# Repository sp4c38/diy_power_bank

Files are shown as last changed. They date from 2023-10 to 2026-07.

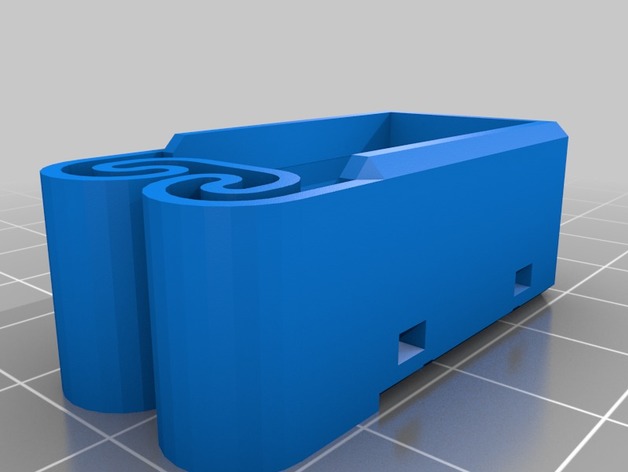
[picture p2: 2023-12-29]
3D Printed Parts/Battery Holder/Try 1/Flexing_battery_holders_with_integrated_spring_456900/images/flexbatter14250x1.jpg

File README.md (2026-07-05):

# DIY Power Bank

This repository contains the project files for my custom power bank, including the PCB design and fabrication files, firmware, iOS app, and 3D-printable enclosure parts.

The files are provided for anyone interested in the project or who wants to learn from it. This is not a complete step-by-step build guide.

[Project showcase](https://www.space8.me/custom-power-bank.html)

Lithium-ion batteries can be dangerous. The files are provided as-is and should only be used with appropriate knowledge and safety precautions.

## License

This project is available under the [MIT License](LICENSE).

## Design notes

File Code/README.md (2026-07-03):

# Powerbank Firmware and App

Firmware for the Arduino Nano 33 BLE that supervises the BQ76920-based power
bank PCB, plus the native SwiftUI iOS app that talks to it over BLE.

## Layout

- `PowerbankFirmware/` - Arduino sketch and C++ source files.
- `Powerbank/` - SwiftUI iOS app.
- `Getting Started with Bluetooth Low Energy.pdf` - BLE reference material.
- `requirements.txt` - historical dependency note from the old setup.

## Firmware Architecture

- `Bq76920Driver` owns CRC I2C, calibration, raw ADC reads, FET control,
  protection registers, balancing, fault clearing and SHIP mode.
- `PackMonitor` converts/filter readings and marks telemetry untrusted if cell
  measurements jump or become implausible.
- `SafetyPolicy` decides whether charge, discharge and balancing are allowed.
- `Balancer` performs conservative one-cell-at-a-time passive balancing.
- `PowerManager` turns the output off after idle and requests SHIP after very
  long idle.
- `BLEApp` exposes telemetry and guarded commands to the iOS app.
- `SerialConsole` mirrors the app commands for bench testing.

## Board

- Board: Arduino Nano 33 BLE
- FQBN: `arduino:mbed_nano:nano33ble`
- Current serial port: `/dev/cu.usbmodem112201`
- Serial baud rate used by the old firmware: `9600`

## Dependencies

Installed through Arduino CLI:

- `ArduinoBLE`
- `ArduinoLog`

## Useful Commands

List connected boards:

```sh
'/Applications/Arduino IDE.app/Contents/Resources/app/lib/backend/resources/arduino-cli' board list
```

Open the serial monitor:

```sh
'/Applications/Arduino IDE.app/Contents/Resources/app/lib/backend/resources/arduino-cli' monitor -p /dev/cu.usbmodem112201 -c baudrate=9600
```

Serial commands:

- `help` - print the command list.
- `status` - print state, FET status, current, pack voltage, die temperature and cell voltages.
- `faults` - print BQ76920 fault/status bits.
- `raw` - print raw ADC/register diagnostics.
- `clear_faults` - clear UV, OV, SCD and OCD fault bits.
- `output_on` / `output_off` - request the normal discharge/output path.
- `ship!` - enter BQ76920 SHIP mode. The `!` is intentional confirmation.
- `charge_on!` / `charge_off` - developer CHG FET override.
- `balance_off` - force all cell balancing off.

Balancing is automatic only when readings are trusted, cells are near the top of
charge, current is near idle, and only one cell needs bleeding.

Compile the firmware:

```sh
'/Applications/Arduino IDE.app/Contents/Resources/app/lib/backend/resources/arduino-cli' compile --fqbn arduino:mbed_nano:nano33ble Code/PowerbankFirmware
```

Upload the firmware:

```sh
'/Applications/Arduino IDE.app/Contents/Resources/app/lib/backend/resources/arduino-cli' upload -p /dev/cu.usbmodem112201 --fqbn arduino:mbed_nano:nano33ble Code/PowerbankFirmware
```

Build the iOS app:

```sh
xcodebuild -project Code/Powerbank/Powerbank.xcodeproj -scheme Powerbank -destination 'platform=iOS Simulator,name=iPhone 17' build
```

## BLE Protocol

Service UUID: `7E571000-40A1-4E31-8E9D-4AC0D8B2A100`

- Telemetry: `7E571001-40A1-4E31-8E9D-4AC0D8B2A100`, read + notify, packed
  little-endian protocol v3 payload. Protocol v2 added full-resolution charge;
  v3 adds the idle-shutdown countdown and new state flags.
- Command: `7E571002-40A1-4E31-8E9D-4AC0D8B2A100`, write, two bytes:
  command id and optional confirmation byte `0xA5`.
- Command result: `7E571003-40A1-4E31-8E9D-4AC0D8B2A100`, read + notify,
  UTF-8 status text.
- Device info: `7E571004-40A1-4E31-8E9D-4AC0D8B2A100`, read, UTF-8 firmware
  and protocol version.
- History control: `7E571005-40A1-4E31-8E9D-4AC0D8B2A100`, read + write +
  notify, requests resumable history streaming and reports the retained range.
- History data: `7E571006-40A1-4E31-8E9D-4AC0D8B2A100`, notify, packed
  ten-minute samples and state-change snapshots split into ordered 20-byte
  chunks so transfer does not depend on a larger negotiated BLE MTU.
- Battery health: `7E571007-40A1-4E31-8E9D-4AC0D8B2A100`, read + notify,
  learned capacity and lifetime aggregate metrics.
- Time sync: `7E571008-40A1-4E31-8E9D-4AC0D8B2A100`, write, Unix time from
  the connected app.

## Persistent Storage

Firmware v0.3 reserves the final 96 KB of internal flash (`0xE8000` through
`0xFFFFF`) for LittleFS. It stores gauge checkpoints, battery-health aggregates,
and a circular buffer of roughly 14 days of history. The firmware disables
storage if its image ever reaches the reserved region; protection and live
telemetry continue without persistence.

The gauge restores its last coulomb count after a restart, then checks it against
trusted resting voltage. Small differences are retained, medium differences are
corrected gradually, and large differences cause a safe voltage-based reseed.

## Bring-Up Notes

2026-06-26:

- Arduino Nano 33 BLE detected on `/dev/cu.usbmodem112201`.
- Firmware compiles and uploads with Arduino CLI.
- Upload may require manually double-tapping reset to enter bootloader mode.
- With cells inserted and BQ76920 booted, I2C/CRC communication works.
- Known-good idle serial baseline:

```text
Pack state: Idle; DSG: true; CHG: true; pack current: -5; pack voltage: 11334
Cell 1: 3787; Cell 2: 3775; Cell 5: 3770
```

- Longer idle observation with the USB-A output module connected is stable at
  roughly `-4` to `-6 mA`, caused by always-on LEDs on that module. This is
  acceptable during bring-up, but the firmware still needs a later low-power
  strategy so that LED load cannot drain the battery pack empty.

Earlier in bring-up, a poorly seated cell/contact produced `Cell 2: 50` and
the firmware correctly disabled discharge. Reseating fixed the reading.

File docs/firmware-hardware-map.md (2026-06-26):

# Firmware Hardware Map

This document captures the firmware-relevant facts extracted from the KiCad
schematic/netlist and existing firmware. It is intended as the starting point
for the power-bank firmware rewrite/audit.

## Source Evidence

- Main schematic: `Circuit/KiCAD Circuit/Powerbank.kicad_sch`
- KiCad netlist export: `Circuit/KiCAD Circuit/Powerbank.xml`
- BOM export: `Circuit/KiCAD Circuit/Bill of Materials.csv`
- Existing firmware: `Code/PowerbankFirmware`

Important caveat: `Powerbank.xml` was exported on 2024-01-12, while the KiCad
project and BOM appear to have changed later. Use this map as a firmware guide,
but verify anything safety-critical against the current schematic/board before
depending on it.

## Main Components

| Ref | Part | Firmware relevance |
| --- | --- | --- |
| U1 | BQ7692003PW | 3-5 cell Li-ion monitor/protector with I2C, CRC, FET control, cell voltage, pack voltage, current, temperature, protection, and balancing registers. |
| U2 | Arduino Nano 33 IoT socket | Firmware host. Current firmware uses Arduino APIs, Wire/I2C, serial logging, and optional ArduinoBLE. |
| Q1, Q3 | IRLB4132PBF NMOS | Pack-side protection FET network controlled through BQ76920 `DSG`/`CHG` circuitry. |
| Q2 | PMOS | Part of charge/discharge gate-control network. |
| R2 | 8 milliohm shunt | Current sense resistor for BQ76920 coulomb/current measurement. |
| SW1 | Pushbutton | Connected into the `TS1`/`VC1` area; likely used for boot/wake behavior. Confirm exact intended behavior before firmware relies on it. |
| SW2 | SPST switch | Connects the switched high-side supply path to Arduino `VIN`. |

## Arduino Pin Map

| Arduino pin | Net / target | Firmware use |
| --- | --- | --- |
| A4 / SDA | BQ76920 `SDA` | I2C data. |
| A5 / SCL | BQ76920 `SCL` | I2C clock. |
| D10 | BQ76920 `ALERT` | Alert/fault signal. Current firmware defines `ALERT_PIN = 10`, but does not actively use an interrupt yet. |
| VIN | Connected through `SW2` | Arduino supply input through the external switch path. |
| GND | Pack/BQ ground | Common reference with BQ76920 `VSS`. |

Unconnected in the netlist: Arduino `3V3`, `+5V`, `A0-A3`, `A6-A7`, `D0-D9`
except `D10`, `D11-D13`, and reset pins. That means the firmware should assume
the Arduino mainly talks to the board over I2C plus `ALERT`; it does not appear
to directly control the USB modules, buck converter, or other external modules.

## Pack Topology

The schematic/netlist describes a 3-cell series pack:

| Physical node | Netlist evidence | BQ76920 sense node |
| --- | --- | --- |
| Pack positive / cell 1 positive | `PACK +`, `CELL_1 +` | Through `Rc1` to `VC5` |
| Cell 1 negative / cell 2 positive | `CELL_1 -`, `CELL_2 +` | Through `Rc2` to tied `VC2`, `VC3`, `VC4` |
| Cell 2 negative / cell 3 positive | `CELL_2 -`, `CELL_3 +` | Through `Rc3` to `VC1` |
| Cell 3 negative / pack/BQ ground | `CELL_3 -`, `GND` | Through `Rc4` to `VC0` / `VSS` |

This matches the existing firmware reading `VC1_HI`, `VC2_HI`, and `VC5_HI`.
The cell labels in firmware should be made explicit because the BQ register
names do not read like physical cell numbers in this 3S configuration.

Proposed firmware naming:

| Firmware name | BQ reading | Physical voltage |
| --- | --- | --- |
| `cellBottomMv` | `VC1` | Bottom cell, between `VC1` and `VC0` |
| `cellMiddleMv` | `VC2` | Middle cell, between `VC2` and `VC1` |
| `cellTopMv` | `VC5` | Top cell, between `VC5` and tied `VC2/VC3/VC4` |

## BQ76920 Connections

| BQ76920 pin/function | Netlist connection | Firmware implication |
| --- | --- | --- |
| `SDA` | Arduino `A4_SDA` | Use `Wire` at BQ address `0x08` with CRC enabled. |
| `SCL` | Arduino `A5_SCL` | Current firmware uses 100 kHz I2C. |
| `ALERT` | Arduino `D10`, pull/filter network `R4`/`C4` | Should be monitored, ideally by interrupt or periodic read. |
| `SRP` / `SRN` | Across 8 milliohm current-sense path via `R1`/`R3` and filter caps | Current calculation must use 8 milliohm sense resistance. |
| `BAT` / `REGSRC` | Through `Rf1`, `Cf1`, diode/resistor network | BQ supply / pack voltage measurement path. |
| `REGOUT` | `C9` decoupling | Internal LDO output; do not treat as Arduino supply unless verified. |
| `CAP1` | `C7` decoupling | BQ internal charge-pump support. |
| `TS1` | `R5`, `R6`, `C5`, `SW1` network | Current firmware reads internal die temperature by keeping `TEMP_SEL = false`; external thermistor behavior needs verification. |
| `CHG` | Q2 source / gate-control network | Controls charge FET behavior indirectly. |
| `DSG` | Q1 gate through `R7` | Controls discharge FET behavior. |

## Protection FET / Pack Path

The netlist shows a low-side protection/sense arrangement:

- `PACK -` connects to Q3 source and `R8`.
- Q1 and Q3 drains are tied together.
- Q1 source connects to the current-sense/shunt side through R2 and the SRN
  filter network.
- BQ `DSG` drives Q1 gate through the `R7` network.
- BQ `CHG` drives Q2, which in turn affects Q3 gate through the `R8` network.

Firmware should therefore treat `DSG_ON` and `CHG_ON` as the authoritative BQ
control bits for enabling/disabling discharge and charge. It should not assume
direct Arduino GPIO control of the power path.

## Existing Firmware Constants To Recheck

Current values in `Code/PowerbankFirmware/register.h`:

| Constant | Current value | Meaning |
| --- | ---: | --- |
| `upperVoltageLimit` | 4190 mV | Firmware charge/balance limit. |
| `lowerVoltageLimit` | 2600 mV | Firmware discharge cutoff threshold. |
| `cvCurrentCutOff` | 200 mA | Constant-voltage completion threshold. |
| `allowedBalancingDifference` | 30 mV | Cell delta before balancing starts. |
| `balancingDifference` | 5 mV | Cell delta target before balancing stops. |
| `dischargingThreshold` | -50 mA | Current below this is considered discharging. |
| `currentSenseResistance` | 8 milliohm | Matches BOM value for R2. |
| `I2C_BQ76920_ADDRESS` | `0x08` | BQ7692003PW with CRC enabled. |
| `ALERT_PIN` | `10` | Matches Arduino D10 connection. |

These are plausible, but should be reviewed before final firmware because they
define real battery safety behavior.

## Existing Code Cross-Check

The old firmware is useful evidence because it reportedly worked on the real
PCB. Comparing it against the schematic/netlist shows that the core assumptions
line up:

| Topic | Existing firmware | Circuit evidence | Result |
| --- | --- | --- | --- |
| BQ device/address | `I2C_BQ76920_ADDRESS = 0x08` | `U1 = BQ7692003PW`, CRC-enabled variant expected by comments/code | Consistent. |
| I2C pins | `SDA_PIN = 18`, `SCL_PIN = 19`; `Wire.begin()` uses board defaults | BQ `SDA` -> Arduino `A4_SDA`, BQ `SCL` -> Arduino `A5_SCL` | Consistent. Pin constants are currently documentation only. |
| Alert pin | `ALERT_PIN = 10` | BQ `ALERT` -> Arduino `D10` | Consistent, but old firmware does not actively use the pin. |
| Current shunt | `currentSenseResistance = 8` milliohm | BOM: `R2 = 8m`; netlist places R2 in the SRP/SRN current path | Consistent. |
| Cell readings | Reads `VC1_HI`, `VC2_HI`, `VC5_HI` | 3S topology uses BQ nodes `VC0`, `VC1`, tied `VC2/VC3/VC4`, and `VC5` | Consistent. |
| Balancing bits | Uses `CB1`, `CB2`, `CB5` | Same BQ cell nodes used for the 3S measurement stack | Consistent with the selected BQ nodes. |
| FET control | Uses BQ `SYS_CTRL2` bits `DSG_ON` and `CHG_ON` | BQ `DSG` and `CHG` feed the MOSFET gate-control network | Consistent. |
| Temperature mode | `TEMP_SEL = false`; reads `TS1_HI` as internal die temperature | TS1 has a resistor/capacitor/switch network, but old code worked with internal temperature mode | Consistent for old behavior; external temperature use remains unverified. |
| Boot/shutdown | Assumes BQ is already booted; implements BQ SHIP sequence | Hardware includes `SW1`/`SW2`, and Arduino has no direct GPIO control of the power path | Consistent with manual wake/power hardware. |

No hardware-code mismatch was found in the essential firmware-facing
connections. The things to improve are mostly software robustness, clarity, and
power management rather than correcting the basic hardware model.

Live bring-up on 2026-06-26 confirmed this: after reseating the cells, the BQ
reported a stable idle baseline of about 11.33 V pack voltage with cell readings
`VC1=3787 mV`, `VC2=3775 mV`, and `VC5=3770 mV`; both `DSG` and `CHG` were on,
and current was near zero.

Minor code issues to clean up later, without changing hardware assumptions:

- `readRegisters()` and `writeRegister()` accept an I2C address parameter but
  internally use the global BQ address in a couple of places. This is harmless
  for this single-chip project, but confusing.
- Cell labels are currently logged as `Cell 1`, `Cell 2`, and `Cell 5`, matching
  BQ register names rather than a user-facing 3-cell pack view.
- `ALERT_PIN` is defined but not yet used for interrupt-driven fault handling
  or low-power wake behavior.
- The firmware waits forever for serial in `setup()`, which was fine for bench
  testing but not for standalone use.

## BQ Registers Already Used

The existing firmware already touches these BQ76920 functions:

- `CC_CFG`: written to `0x19` during setup.
- `ADCGAIN1`, `ADCGAIN2`, `ADCOFFSET`: used for voltage calibration.
- `VC1_HI`, `VC2_HI`, `VC5_HI`: cell voltage readings.
- `BAT_HI`: pack voltage.
- `CC_HI`: current/coulomb-counter reading.
- `TS1_HI`: temperature reading.
- `SYS_STAT`: fault flags.
- `SYS_CTRL1`, `SYS_CTRL2`: ADC, CC, CHG, DSG, SHIP sequence.
- `PROTECT1`, `PROTECT2`, `PROTECT3`, `OV_TRIP`, `UV_TRIP`: protection thresholds.
- `CELLBAL1`: cell balancing.

## Firmware Design Implications

1. The Arduino should be treated as a supervisor/UI node. The BQ76920 is the
   actual battery protection and measurement device.
2. Serial-only firmware should come before BLE. We need a trusted status loop
   first: BQ init, readings, fault handling, FET state, and SHIP mode.
3. The `ALERT` pin should become part of the safety loop. Polling `SYS_STAT`
   alone is useful, but `ALERT` lets firmware react quickly and sleep more
   efficiently.
4. Current firmware reads only internal die temperature. If the TS1 network was
   intended as an external thermistor or wake button path, that behavior needs
   a bench check.
5. Low-power behavior must account for hardware outside firmware control. If
   USB modules or converters draw idle current independently, firmware sleep
   alone will not be enough.
6. The BQ SHIP mode sequence is already implemented and should be preserved,
   but we need a clear policy for when firmware enters it.
7. BLE should be telemetry-first: expose pack status, cell voltages, current,
   temperatures, FET states, faults, balancing state, and uptime. Control
   commands should be restricted or guarded.

## Open Questions For Bench Verification

- Does `SW1` wake the BQ from SHIP mode, boot the pack, or serve another role?
- Does `SW2` fully remove Arduino power, or only switch part of the supply path?
- What is the actual idle current with CHG/DSG enabled and no load?
- What is the actual idle current with Arduino awake, asleep, BLE advertising,
  and BLE connected?
- Are the USB-A, USB-C, and buck modules powered from `PACK +` / `PACK -`
  after the protection FETs, and do they have enable pins not present in the
  KiCad netlist?
- Is there an external temperature sensor fitted, or should firmware only rely
  on BQ die temperature?
- Which physical cell should be displayed as cell 1 in the user interface:
  bottom-to-top electrical order, or the labels used in the schematic?

## Suggested First Firmware Milestone

Create a serial-only supervisor firmware that:

1. Initializes BQ76920 safely.
2. Verifies I2C/CRC communication.
3. Reads and prints all three cell voltages, pack voltage, current, temperature,
   `SYS_STAT`, and CHG/DSG state.
4. Exposes serial commands: `status`, `faults`, `clear_faults`, `ship`,
   `charge_on`, `charge_off`, `discharge_on`, `discharge_off`, and `balance_off`.
5. Keeps all balancing disabled unless explicitly testing it.
6. Never enables charge/discharge if voltage, current, temperature, or BQ fault
   status is outside the configured safety envelope.

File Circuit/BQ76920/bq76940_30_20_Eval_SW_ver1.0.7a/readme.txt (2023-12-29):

bqMAXIMO Windows installation software for bq769X0 AFEs

1. This program executes on Windows XP, Vista, and 7 32 or 64bit operating systems.  This installer assumes that a working EV2300 or EV2400 communications adapter with drivers is already installed on system.

2. Execute setup.exe.  This installs bqMAXIMO and all support components in c:\program files\Texas Instruments\bqMAXIMO directory.  A bqMAXIMO shortcut is placed on the desktop.  This shortcut can be used to execute the program after installation.  Other shortcuts are installed under "All Programs" "Texas Instruments".

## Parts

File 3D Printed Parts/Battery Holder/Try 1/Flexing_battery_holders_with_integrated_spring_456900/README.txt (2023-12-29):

Flexing battery holders with integrated spring by enif on Thingiverse: https://www.thingiverse.com/thing:456900

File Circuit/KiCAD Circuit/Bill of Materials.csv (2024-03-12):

Reference | Value | Footprint | Qty | DNP | Mouser
A1 | Arduino_Nano_33_IoT_Socket | Arduinos:Arduino_Nano_33_IoT_Socket | 1
C1,C2,C3,C6,C8 | 0.1uF | K104K10X7RF53H5:K104K10X7RF53H5_VIS | 5 |  | 594-K104K10X7RF53H5
C4 | 470pF | K471K10X7RF5UH5:K471K10X7RF5UH5_VIS | 1 |  | 594-K471K10X7RF5UH5
C5 | 4700pF | C410C472K1R5TA:CAP_C410C_AX_X7R_AXIMAX_KEM | 1 |  | 80-C410C472K1R
C7,Cc1,Cc2,Cc3,Cc4 | 1uF | K105K20X7RF5TH5:K105K20X7RF5TH5_VIS | 5 |  | 594-K105K20X7RF5TH5
C9 | 4.7uF | FG24X7R1E475KRT06:CAP_FG24_TDK | 1 |  | 810-FG24X7R1E475KRT6
Cf1 | 2.2uF | FG18X5R1E225KRT06:CAP_FG18_TDK | 1 |  | 810-FG18X5R1E225KRT6
D1,D2 | D | Custom Footprints:1N4149TR | 2 |  | 512-1N4149
D3 | TVS Diode 17.1V | Diode_THT:D_DO-41_SOD81_P7.62mm_Horizontal | 1 |  | 576-P4KE20A
H1 | BATT+ | Custom Footprints:Power Connection Pads | 1
H2 | BATT- | Custom Footprints:Power Connection Pads | 1
H7 | PACK+ | Custom Footprints:Power Connection Pads | 1
H8 | PACK- | Custom Footprints:Power Connection Pads | 1
J1 | EBWA-04-A | Custom Footprints:EBWA-04-A | 1 |  | 737-EBWA-04-A
Q1,Q3 | NMOS | Custom Footprints:IRLB4132PBF | 2 |  | 942-IRLB4132PBF
Q2 | PMOS | Custom Footprints:TO-92_MC_MCH | 1 |  | 689-VP3203N3-G
R1,R3,Rf1 | 100 | RNF14FTD100R:STA_RNF14_STP | 3 |  | 708-RNF14FTD100R
R2 | 8m | 14AFR008E:RES_14A_OHM | 1 |  | 588-14AFR008E
R4 | 499k | MFR-25FBF52-499K:YAG_MF25_YAG | 1 |  | 603-MFR-25FBF52-499K
R5,R6,Rd1,Rd2 | 10k | RNF18FTD10K0:STA_RNF18_STP | 4 |  | 708-RNF18FTD10K0
R7,R8 | 1M | MFR-25FRF52-1M:YAG_MF25_YAG | 2 |  | 603-MFR-25FRF521M
Rc1,Rc2,Rc3,Rc4 | 50 | CMF5550R000FKEK70:RES_CMF07_VIS | 4 |  | 71-CMF5550R000FKEK70
SW1 | SW_Push | Custom Footprints:Switch Pads | 1
SW2 | SW_SPST | Custom Footprints:Switch Pads | 1
U1 | BQ7692003PW | BQ7692003PW:PW0020A_N | 1 |  | 595-BQ7692003PW

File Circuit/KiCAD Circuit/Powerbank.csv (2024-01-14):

# | Reference | Qty | Value | Footprint | DNP
1 | C1, C2, C3, C6, C8, C10, C11 | 7 | 0.1μF
2 | C4 | 1 | 470pF
3 | C5 | 1 | 4700pF
4 | C7, Cc1, Cc2, Cc3, Cc4 | 5 | 1μF
5 | C9 | 1 | 4.7μF
6 | CELL_1, CELL_2, CELL_3 | 3 | ~
7 | Cf1 | 1 | 2.2μF
8 | D1, D3 | 2 | D
9 | D2 | 1 | TVS Diode 30V
10 | Q1, Q3 | 2 | NMOS
11 | Q2 | 1 | PMOS
12 | R1, R3, Rf1 | 3 | 100Ω
13 | R2 | 1 | 8mΩ
14 | R4 | 1 | 500kΩ
15 | R5, R6, Rd1, Rd2 | 4 | 10kΩ
16 | R7, R8 | 2 | 1MΩ
17 | Rc1, Rc2, Rc3, Rc4 | 4 | 50Ω
18 | SW1 | 1 | SW_Push
19 | SW2 | 1 | SW_SPST
20 | U1 | 1 | BQ7692003PW | BQ7692003PW:PW0020A_N
21 | U2 | 1 | Arduino_Nano_v3.x | Arduinos:Arduino_Nano_33_IoT_Socket

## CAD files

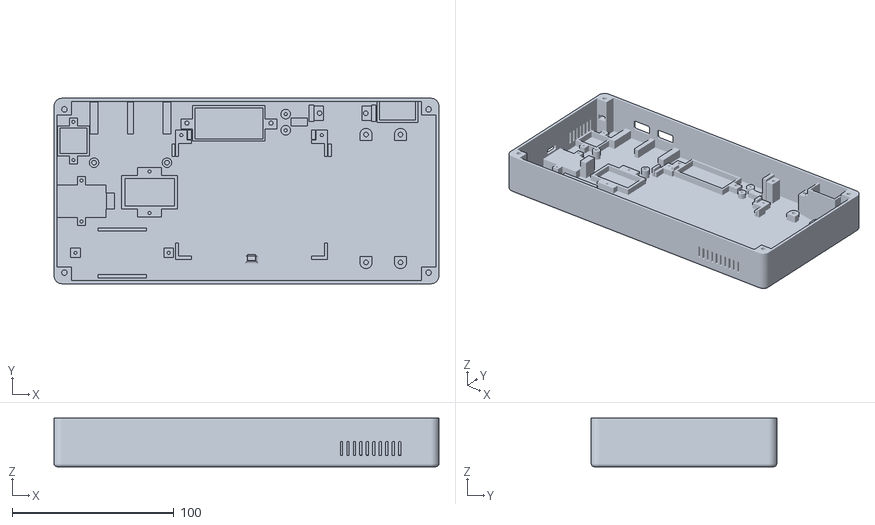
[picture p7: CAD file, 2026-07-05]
3D Printed Parts/Case/Base_Frame v169_Main Body.stl
238.0 x 114.7 x 30.0

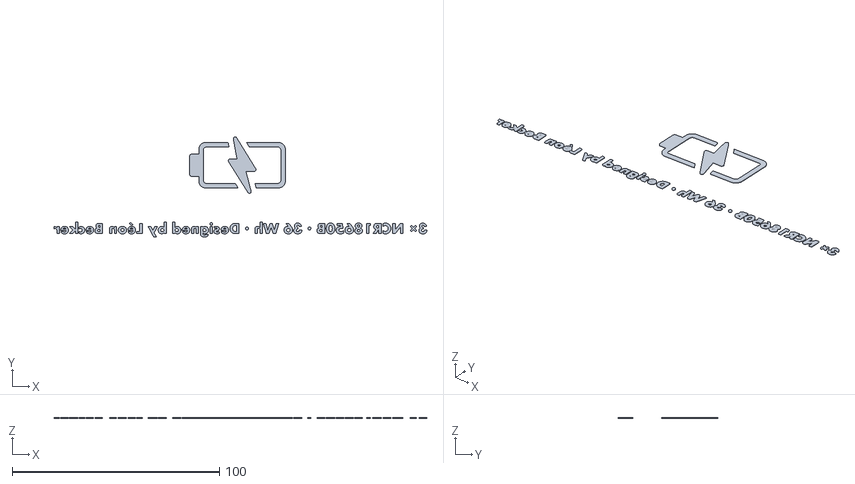
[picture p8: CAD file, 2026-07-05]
3D Printed Parts/Case/Main Body Bottom Text.stl
179.9 x 48.4 x 0.5

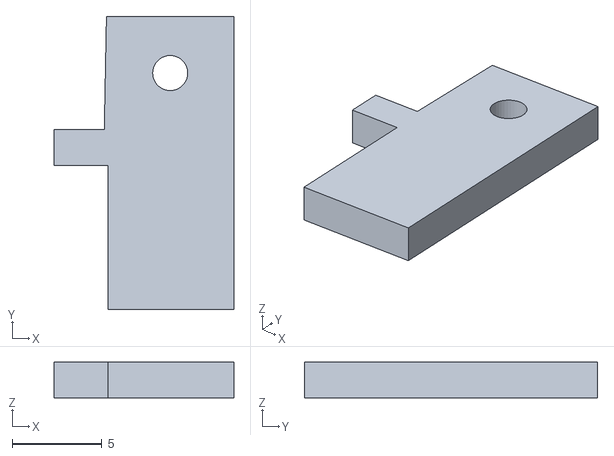
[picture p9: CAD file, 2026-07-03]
3D Printed Parts/Case/Base_Frame v169_Mainboard Holder 1.stl
10.0 x 16.3 x 2.00

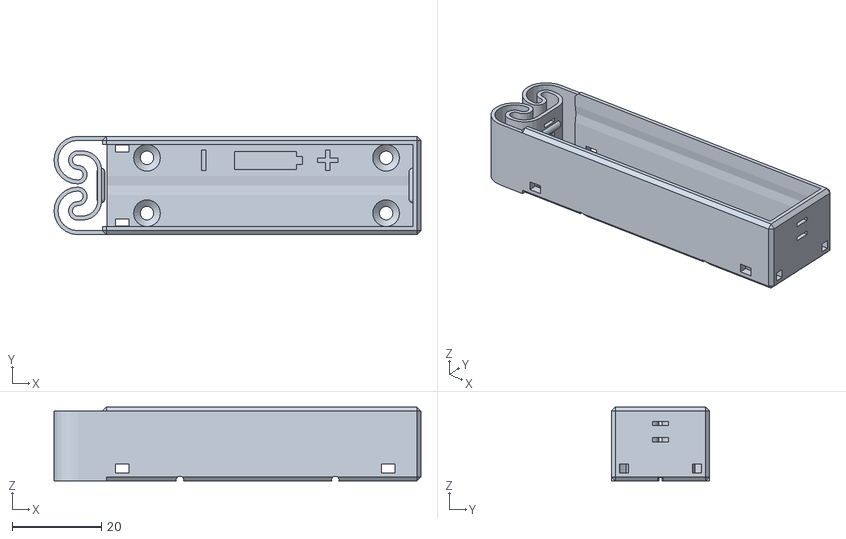
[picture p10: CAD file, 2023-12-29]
3D Printed Parts/Battery Holder/Try 1/1x NCR18650B Protected Holder.stl
82.1 x 22.0 x 16.5

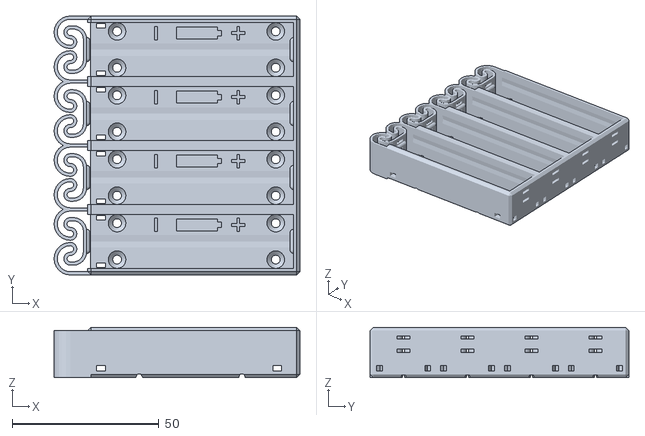
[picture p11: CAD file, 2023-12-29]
3D Printed Parts/Battery Holder/Try 1/Flexing_battery_holders_with_integrated_spring_456900/files/flexbatter18700x4.stl
83.7 x 88.2 x 17.2

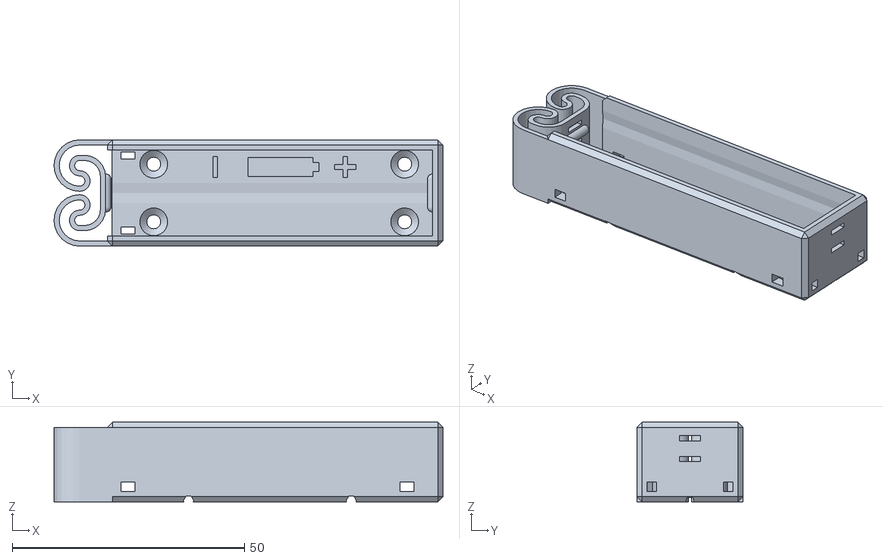
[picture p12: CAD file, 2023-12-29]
3D Printed Parts/Battery Holder/Try 1/Flexing_battery_holders_with_integrated_spring_456900/files/flexbatter18700x1.stl
83.7 x 22.9 x 17.2

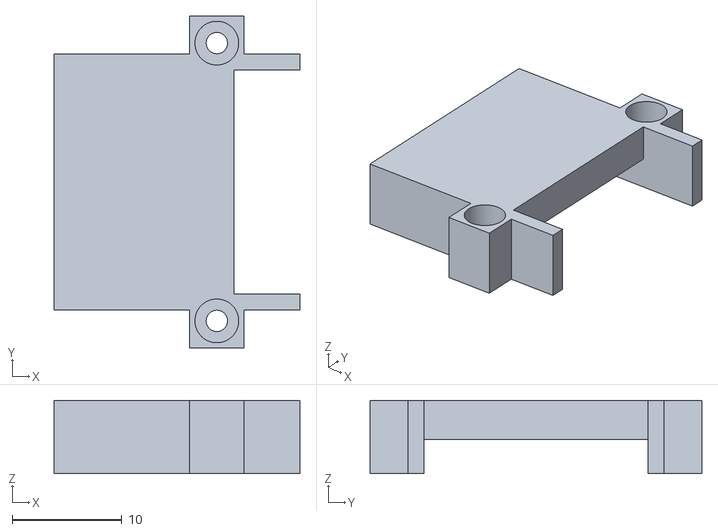
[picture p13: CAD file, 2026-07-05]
3D Printed Parts/Case/Base_Frame v169_USB-C Input Top.stl
22.4 x 30.3 x 6.70

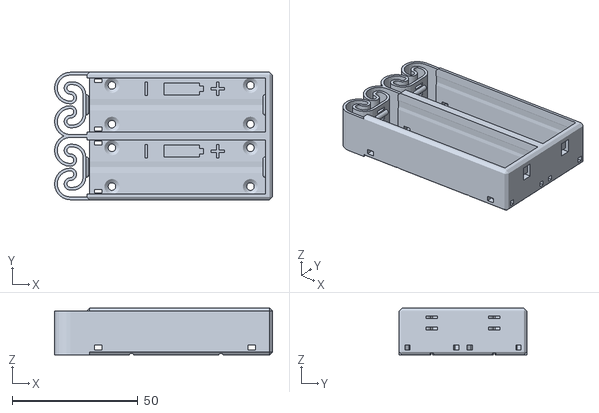
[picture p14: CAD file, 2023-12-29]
3D Printed Parts/Battery Holder/Try 1/Flexing_battery_holders_with_integrated_spring_456900/files/flexbatter21700x2.stl
86.6 x 50.6 x 18.5

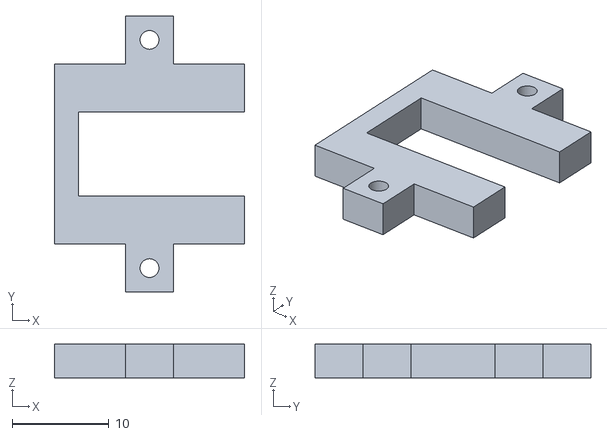
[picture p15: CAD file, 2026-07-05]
3D Printed Parts/Case/Base_Frame v169_Cable Hub Top.stl
19.7 x 28.6 x 3.50

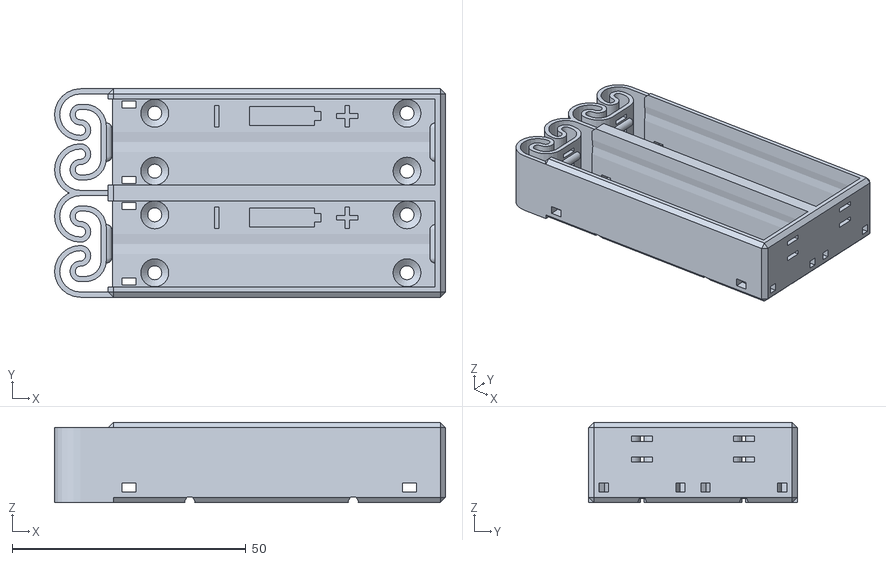
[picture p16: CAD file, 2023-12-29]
3D Printed Parts/Battery Holder/Try 1/Flexing_battery_holders_with_integrated_spring_456900/files/flexbatter18700x2.stl
83.7 x 44.6 x 17.2

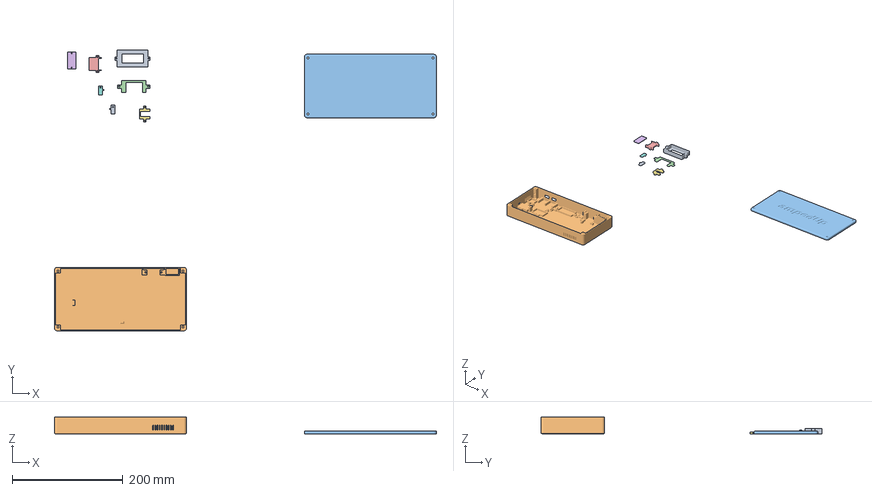
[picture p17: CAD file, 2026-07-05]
3D Printed Parts/Case/Case.3mf
688.5 x 506.1 x 30.0 mm
Base_Frame v169_Body116.stl
Base_Frame v169_Main Body
Lid.stl
Base_Frame v169_MOSFET Top.stl
Base_Frame v169_USB-C Input Top.stl
Base_Frame v169_Diode Cover.stl
Base_Frame v169_Cable Hub Top.stl
Base_Frame v169_Mainboard Holder 2.stl
Base_Frame v169_Mainboard Holder 1.stl

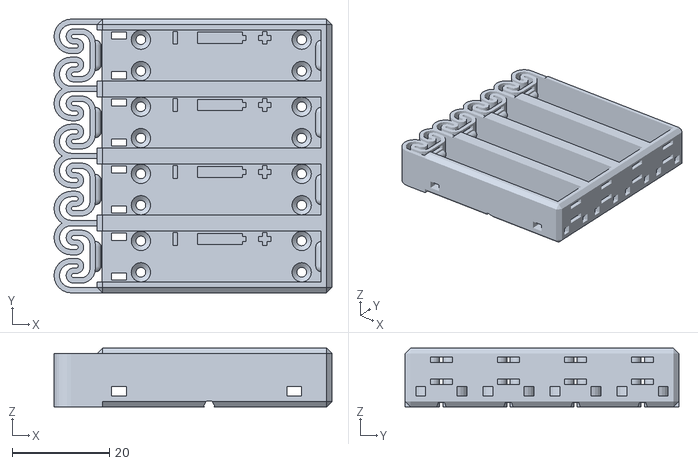
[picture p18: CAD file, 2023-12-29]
3D Printed Parts/Battery Holder/Try 1/Flexing_battery_holders_with_integrated_spring_456900/files/flexbatterAAAx4.stl
57.2 x 56.4 x 12.1

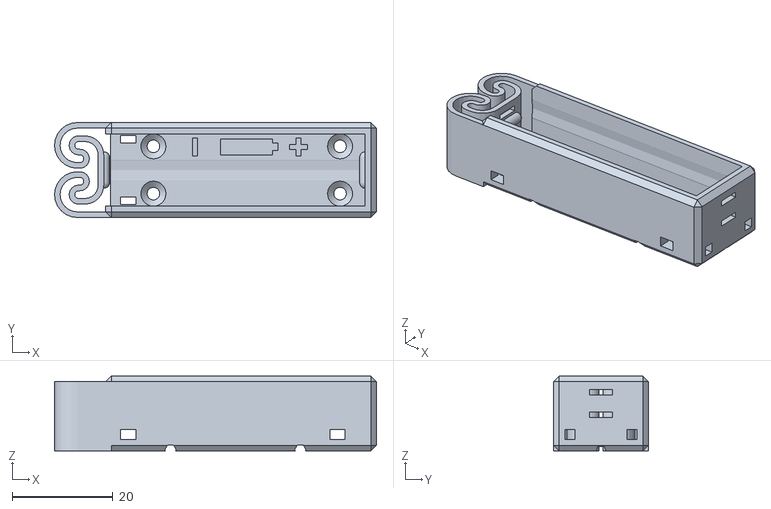
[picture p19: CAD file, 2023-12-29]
3D Printed Parts/Battery Holder/Try 1/Flexing_battery_holders_with_integrated_spring_456900/files/flexbatterAAx1.stl
64.0 x 18.9 x 14.9

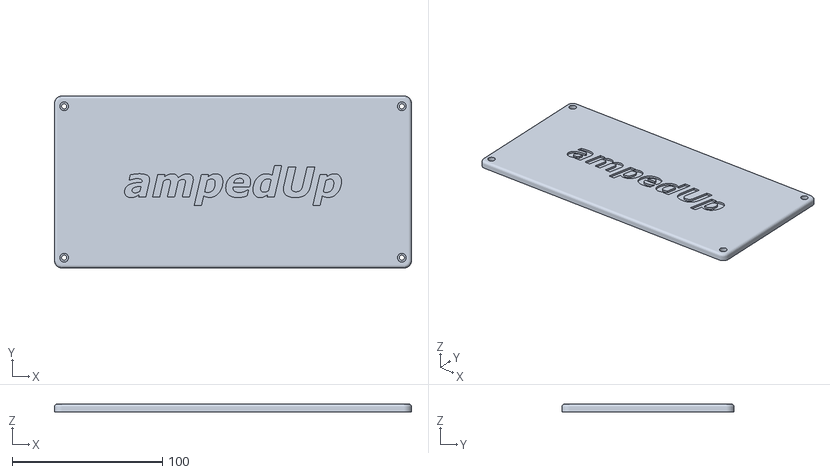
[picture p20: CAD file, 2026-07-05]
3D Printed Parts/Case/Lid.stl
238.0 x 114.7 x 5.50

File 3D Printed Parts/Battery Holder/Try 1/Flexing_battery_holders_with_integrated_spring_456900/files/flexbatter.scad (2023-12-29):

//////////////////////////////////////////////////////////////////////////////////////
///
///  FLEXBATTER: Flexing battery holder with built-in spring
///
///  This file generates battery holders for arbitrary cylindrical sizes.
///  The number of batteries and their size is fully parametrized.
///
///  The usual metallic spring at the minus pole is replaced by a
///  flexible printed spring, which is pressing the contacts firmly to 
///  the battery.
///
///  The contacts for the plus and minus pole can easily be made by
///  a few windings of the uninsulated ends of the connecting wires.
///  Each battery compartment contains are several holes to the outside
///  as well ad to the neighboring compartments, through which connecting
///  wires can be passed for easy configuring of parallel, serial or
///  balanced-serial battery packs.
///  
///  The preconfigured battery sizes are:
///  AA, AAA, C, D, 18650(Li-Ion), 18650P(protected Li-Ion), CR123A(16340)
///  
///  Given that the printed plastic spring needs to be flexible, ABS is the material
///  of choice here.
///
//////////////////////////////////////////////////////////////////////////////////////
///
///  2014-09-09 Heinz Spiess, Switzerland
///
///  released under Creative Commons - Attribution - Share Alike licence (CC BY-SA)
//////////////////////////////////////////////////////////////////////////////////////

// build a cube with chamfered edges
module chamfered_cube(size,d=1){
   hull(){
     translate([d,d,0])cube(size-2*[d,d,0]);
     translate([0,d,d])cube(size-2*[0,d,d]);
     translate([d,0,d])cube(size-2*[d,0,d]);
   }
}


// draw an arc width height h between radius r1..r2 and angles a1..a2
module arc(r1,r2,h,a1=0,a2=0){
     if(a2-a1<=180){
        difference(){
           cylinder(r=r2,h=h);
           translate([0,0,-1])cylinder(r=r1,h=h+2);
	   rotate(a2)translate([-r1-r2,0,-1])cube([2*(r1+r2),2*(r1+r2),h+2]);
	   rotate(a1+180)translate([-r1-r2,0,-1])cube([2*(r1+r2),2*(r1+r2),h+2]);
        }
     } else {
           difference(){
              cylinder(r=r2,h=h);
              translate([0,0,-1])cylinder(r=r1,h=h+2);
              intersection(){
	       rotate(a2)translate([-r1-r2,0,-1])cube([2*(r1+r2),2*(r1+r2),h+2]);
	       rotate(a1+180)translate([-r1-r2,0,-1])cube([2*(r1+r2),2*(r1+r2),h+2]);
	      }
           }
     }
}

/////////////////////////////////////////////////////////////////////////////////
// sline - generate a "snake line" of width w and height h 
// with a arbitrary sequence of segments defined by a radius and a turning angle
//
//   angle[i] > 0  left turn / counter-clockwise
//   angle[i] < 0  left turn / clockwise
//   angle[i] = 0  straight segment with length radius[i]
//
/////////////////////////////////////////////////////////////////////////////////
// Heinz Spiess, 2014-09-06 (CC BY-SA)
/////////////////////////////////////////////////////////////////////////////////
module sline(angle,radius,i,w,h){
   scale([angle[i]>=0?1:-1,1,1])
      assign(r=abs(radius[i]))assign(a=angle[i])
         translate([a?r:0,0,0]){
	    translate([-w/2,-r-0.01,0])cube([w,0.02,h]); // tiny overlap!
            if(a)arc(r-w/2,r+w/2,0,a,h=h);
	    else if(r>0)translate([-w/2,-r,0])cube([w,r,h]);
      if(i+1<len(angle))
           rotate(angle[i])
	      translate([a?-r:0,a?0:-r,0])
	         sline(angle,radius,i+1,w,h);
  }
}

//////////////////////////////////////////////////////////////////////////////////
//
//  FLEXBATTER:  Flexing battery holder with integrated plastic spring
//
//////////////////////////////////////////////////////////////////////////////////
module flexbatter(n=1,l=65,d=18,hf=0.75,r=4,shd=3,eps=0.28,el=0,xchan=[1/4,3/4],$fn=24){
ew=0.45;   // extrusion width
eh=0.25;   // extrusion height
w = 4*ew;  // case wall thickness
ws = 2*ew; // spring wall thickness
ch = w-ws; // edge chamfering
deepen=0; //deepening for side grip of batteries
//el = 0;  // extra length in spring
//eps = 0.28;
//shd = 3; // screw hole diameter
//hf=0.75;
//xchan=[1/4,3/4]; // relative position of traversal wire channels

r = d/5+2*ws; // linear spring length (depends on sline() call!)

   for(i=[0:n-1])translate([0,i*(d+w+ws),0]){ // generate n battery cases
      difference(){
         
         union(){
            difference(){
               // main body
               translate([0,-w-d/2,0])
	          chamfered_cube([l+w,d+2*w+(i<n-1?ws:0),hf*d+w+ch],ch);
	       // main cavity
               translate([-2,-d/2,w])cube([2+l,d,d+1]);
	       // cavity for locating plastic spring
               translate([-1,-d/2,-1])cube([2,d,d+w+2]);
	       // small cylindrical carving of walls and bottom
	       if(eps>0)translate([-1,0,d/2+w])rotate([0,90,0])cylinder(r=d/2+eps,h=l+1);
            }
      
            // plastic spring for minus pole
            for(sy=[-1,1])scale([1,sy,1])assign(D=d+2*w-2*ws-0.7){
               translate([ch,d/2+w-ws/2,0])rotate(-90)
		  //sline([90,0,120,90,120,90,0],[d/8+2,d/6,d/8-1,d/8,-d/8,d/8,d/2],0,ws,hf*d+w);
		  sline([0,180,0,180,0,-180,0,90,0],[r+ch+el,D/4,el,D/12,el/2,D/12,1+el/2,D/5,D/3],0,ws,hf*d+w);


            }
         }
      
         // lower and upper holes for contacts
         for(z=[-2*ws,2*ws])
            translate([-2*ws,-w,w-ws/2+d/2+z])cube([l+2*w+2,2*w,ws]);
      
         // longitudinal bottom wire channel
         translate([-2*ws,0,0])rotate([0,90,0])cylinder(r=w/2,h=l+w+2+r,$fn=5);
      
         // traversal bottom wire channels
         for(x=l*xchan)translate([x,-d/2-w-1,eh]) rotate([-90,0,0])cylinder(r=w/2,h=d+2*w+ws+2,$fn=6);
   
         // grip deepening
	 if(deepen>0)
            translate([w+l/2-0.5,-d/2-w-0.01,w+d+l])
	       rotate([-90,0,0]){
	          cylinder(r=l+deepen*d,h=d+2*w+2*ws+2,$fn=72);
	          if(i==0)cylinder(r1=l+deepen*d+ch,r2=l+deepen*d,h=ch+0.02,$fn=72);
	          if(i==n-1)translate([0,0,d+2*w-ch])cylinder(r2=l+deepen*d+ch,r1=l+deepen*d,h=ch+0.02,$fn=72);

               }
         // conical screw holes in corners
         for(x=[7+shd,l-2*shd])for(y=[-d/2+shd,d/2-shd])
             translate([x,y,-1]){
                cylinder(r=shd/2,h=w+2);
                translate([0,0,w-shd/2+1])cylinder(r1=shd/2,r2=shd,h=shd/2+0.01);
             }

         // holes for wires passing inside
         for(sy=[-1,1])scale([1,sy,1]){
	    translate([l-1,-d/2,w])cube([w+2,2,2]);
            for(x=[3,l-7])translate([x,-d/2-w-ws-1,w])cube([3,w+ws+3,2]); 
            translate([3,-d/2+w/2-0.75,-1])cube([3,1.5,w+2]); 
            translate([-0.5,-d/2+w/2,0])rotate([0,90,0])cylinder(r=w/2,h=6.5,$fn=5);
         }

         // engrave battery symbol
	 translate([w+l/2,d/4+1,w])cube([l/5,d/4.5,4*eh],true);
	 translate([w+l/2+l/10,d/4+1,w])cube([d/7,d/10,4*eh],true);
	 // engrave plus symbol
	 assign(sy=(l>12*shd)?1:-1){ // for short batteries +- on the side
	    translate([w+l/2+l/(sy>0?5:10),sy*(d/4+1),w]){
	       cube([1,d/4,4*eh],true);
	       cube([d/4,1,4*eh],true);
            }
	 // engrave minus symbol
	    translate([w+l/2-l/(sy>0?5:10),sy*(d/4+1),w])
	       cube([1,d/4,4*eh],true);
         }
   
         //correction for middle separators
         //if(i<n-1) translate([-d,d/2+w-ws/2,-1])cube([d,ws/2+0.1,d+2]);
	 //else translate([1,d/2+w,-0.01])cylinder(r1=ch,r2=0,h=ch);
         //if(i>0) translate([-d,-d/2-w-0.1,-1])cube([d,ws/2+0.1,d+2]);
	 //else translate([1,-d/2-w,-0.01])cylinder(r1=ch,r2=0,h=ch);


      }


      // horizontal contact bulges (+ and - pole)
      for(x=[-0.3,l])
         hull()for(y=[-3+el,3-el])
            translate([x,y,w+d/2])sphere(r=ws);
   
      // vertical contact bulge (+ pole only)
      if(0)hull()for(z=[-3+el,3-el])for(x=[0,w-ws])
            translate([l+x,0,w+d/2+z])sphere(r=ws);



   }

}

module flexbatter18650(n=1){
   flexbatter(n=n,l=65.5,d=18.4,hf=0.75,shd=3,eps=0.28);
}  

module flexbatter18650P(n=1){
   flexbatter(n=1,l=69.5,d=18.4,hf=0.75,shd=3,eps=0.28);
}  

module flexbatterCR123A(n=1){
   flexbatter(n=n,l=35.1,d=16.7,hf=0.75,shd=3,xchan=[0.5],eps=0.28);
}  

module flexbatterD(n=1){
   flexbatter(n=n,l=61.5,d=34.0,hf=0.75,shd=3,eps=0.28);
}  

module flexbatterC(n=1){
   flexbatter(n=n,l=51.6,d=26.4,hf=0.75,shd=3,eps=0.28);
}  

module flexbatterAA(n=1){
   flexbatter(n=n,l=51.6,d=14.4,hf=0.80,shd=2.5,el=0.5,eps=0.28);
}  

module flexbatterAAA(n=1){
   flexbatter(n=n,l=46.1,d=10.45,hf=0.84,shd=2,el=1,xchan=[0.5],eps=0);
}  

module flexbatter18650x1(){ // AUTO_MAKE_STL
  flexbatter18650(n=1);
}

module flexbatter18650Px1(){ // AUTO_MAKE_STL
  flexbatter18650P(n=1);
}

module flexbatterCR123Ax1(){ // AUTO_MAKE_STL
  flexbatterCR123A(n=1);
}

module flexbatterAAx1(){ // AUTO_MAKE_STL
  flexbatterAA(n=1);
}

module flexbatterAAAx1(){ // AUTO_MAKE_STL
  flexbatterAAA(n=1);
}

module flexbatterCx1(){ // AUTO_MAKE_STL
  flexbatterC(n=1);
}

module flexbatter18650x2(){ // AUTO_MAKE_STL
  flexbatter18650(n=2);
}

module flexbatterAAx2(){ // AUTO_MAKE_STL
  flexbatterAA(n=2);
}
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

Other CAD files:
3D Printed Parts/Case/Base_Frame v169_Mainboard Holder 2.stl
3D Printed Parts/Battery Holder/Try 1/Flexing_battery_holders_with_integrated_spring_456900/files/flexbatter26650x1.stl
3D Printed Parts/Case/Base_Frame v169_Body116.stl
3D Printed Parts/Battery Holder/Try 1/Flexing_battery_holders_with_integrated_spring_456900/files/flexbatter26650x3.stl
3D Printed Parts/Battery Holder/Try 1/Flexing_battery_holders_with_integrated_spring_456900/files/flexbatter14250x1.stl
3D Printed Parts/Battery Holder/Try 1/Flexing_battery_holders_with_integrated_spring_456900/files/flexbatter18650Px1.stl
3D Printed Parts/Battery Holder/Try 1/Flexing_battery_holders_with_integrated_spring_456900/files/flexbatter18650x1.stl
3D Printed Parts/Battery Holder/Try 1/Flexing_battery_holders_with_integrated_spring_456900/files/flexbatter18650x2.stl
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

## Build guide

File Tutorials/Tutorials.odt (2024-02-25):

Tutorials on how to build a power-bank

- Tutorial 1: https://www.youtube.com/watch?v=xAyOeGTdyX4
- Tutorial 2 (Overkill): https://www.youtube.com/watch?v=adY-S8AH_Jc
- Tutorial 3:
- Tutorial 4:

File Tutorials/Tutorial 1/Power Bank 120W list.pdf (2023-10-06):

Row | Tool list | Num | List of pieces | Num
1 | table Clamp | 1 | 25*8 Aluminum sheet | 2
2 | Fret saw | 1 | Spacer Metal and screw | 8
3 | Hand File | 1 | cellophane | 1
4 | drill | 1 | Voltmeter Ammeter DC 100V 10A | 1
5 | Sharp Tweezer | 1 | Glossy PVC Self | 1
6 | mini angle grinder | 1 | Epoxy resin | 1
7 | caliper | 1 | Battery monitor Display 12-24-36-48Vdc - LY6 | 1
8 | screw driver | 1 | Silicone glue | 0
9 | cutter | 1 | Micro switch 6X6X9MM | 1
10 | Sanding | 1 | DC-DC Booster Converter Module 10-50V 10A 250W | 1
11 | Finger milling Farz | 1 | Thermal silicone paste | 1
12 | multimeter | 1 | Li-Ion Battery 3.7V Size 18650 3350mAh | 6
13 | Soldering tools | 1 | Lithium Battery Charger Protection Board Module 3S 10A | 2
14 | | 0 | Clear nail polish | 1
15 | | 0 | Double sided glue | 1
16 | | 0 | USB Trigger Tester module | 1
17 | | 0 | USB Type-C Female Connector | 1
18 | | 0 | DC Power Adapter 2.5x5.5mm Female Terminal | 1
19 | | 0 | QC4.0-QC3.0 fast charging module 60W USB-C PD Fast Charger | 2
20 | | 0 | Mini On/Off Push-Button Switch | 1
21 | | 0 | Liquid twin glue | 1

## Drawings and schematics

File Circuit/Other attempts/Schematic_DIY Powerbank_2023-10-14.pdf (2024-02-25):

## USB-A OUT

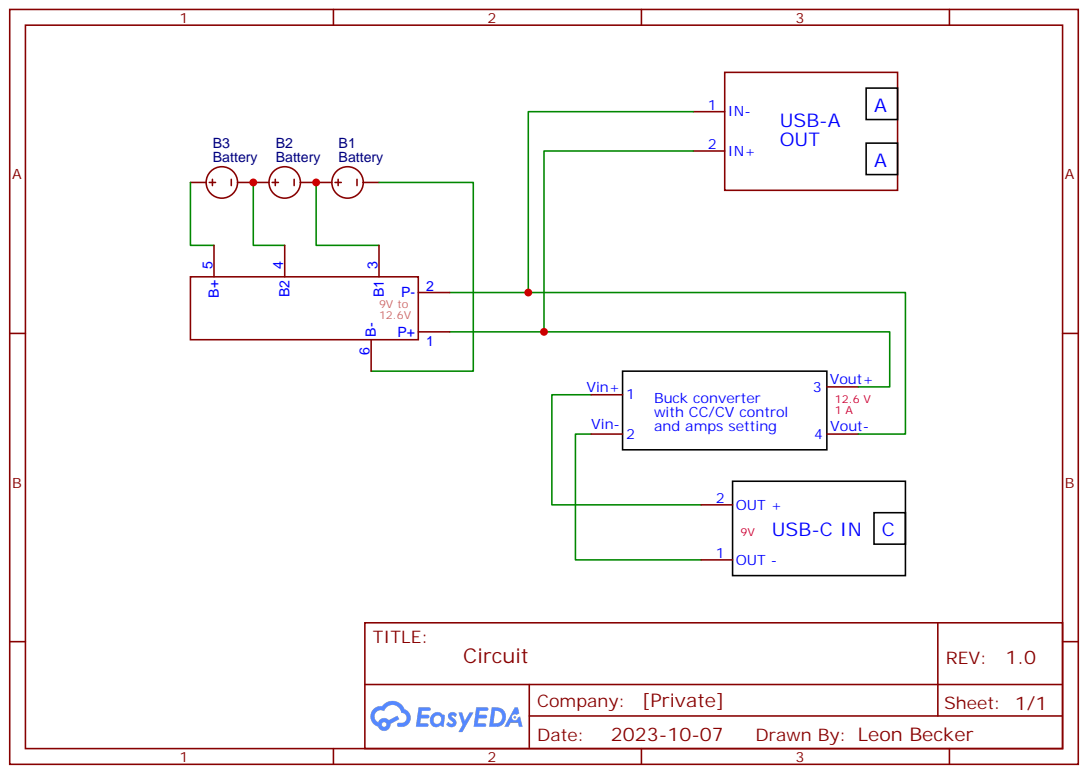
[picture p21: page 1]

Buck converter
with CC/CV control
and amps setting

Drawn By: Leon Becker

## Adjust

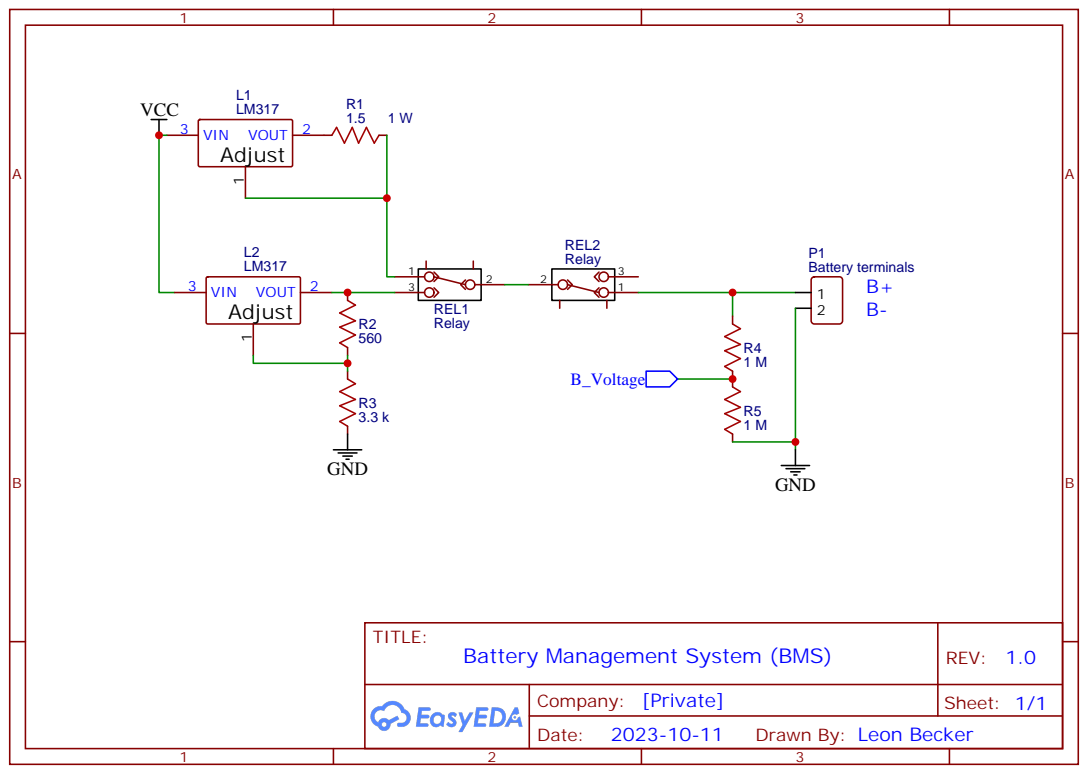
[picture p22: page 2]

Drawn By: Leon Becker

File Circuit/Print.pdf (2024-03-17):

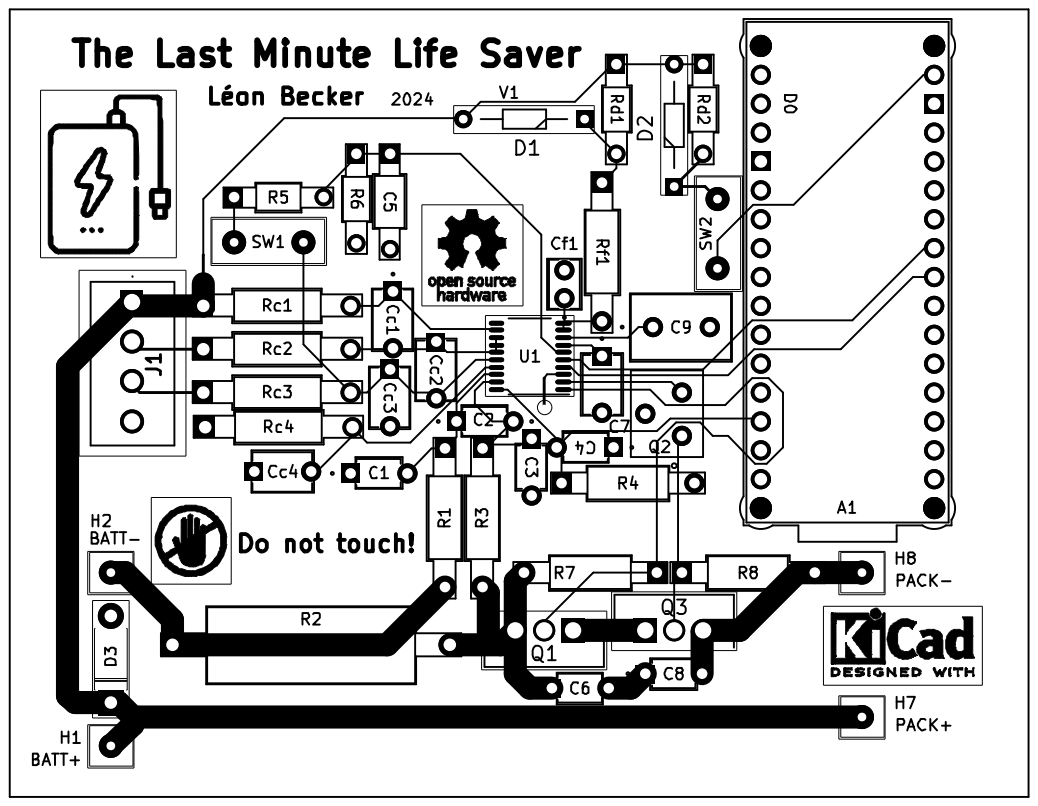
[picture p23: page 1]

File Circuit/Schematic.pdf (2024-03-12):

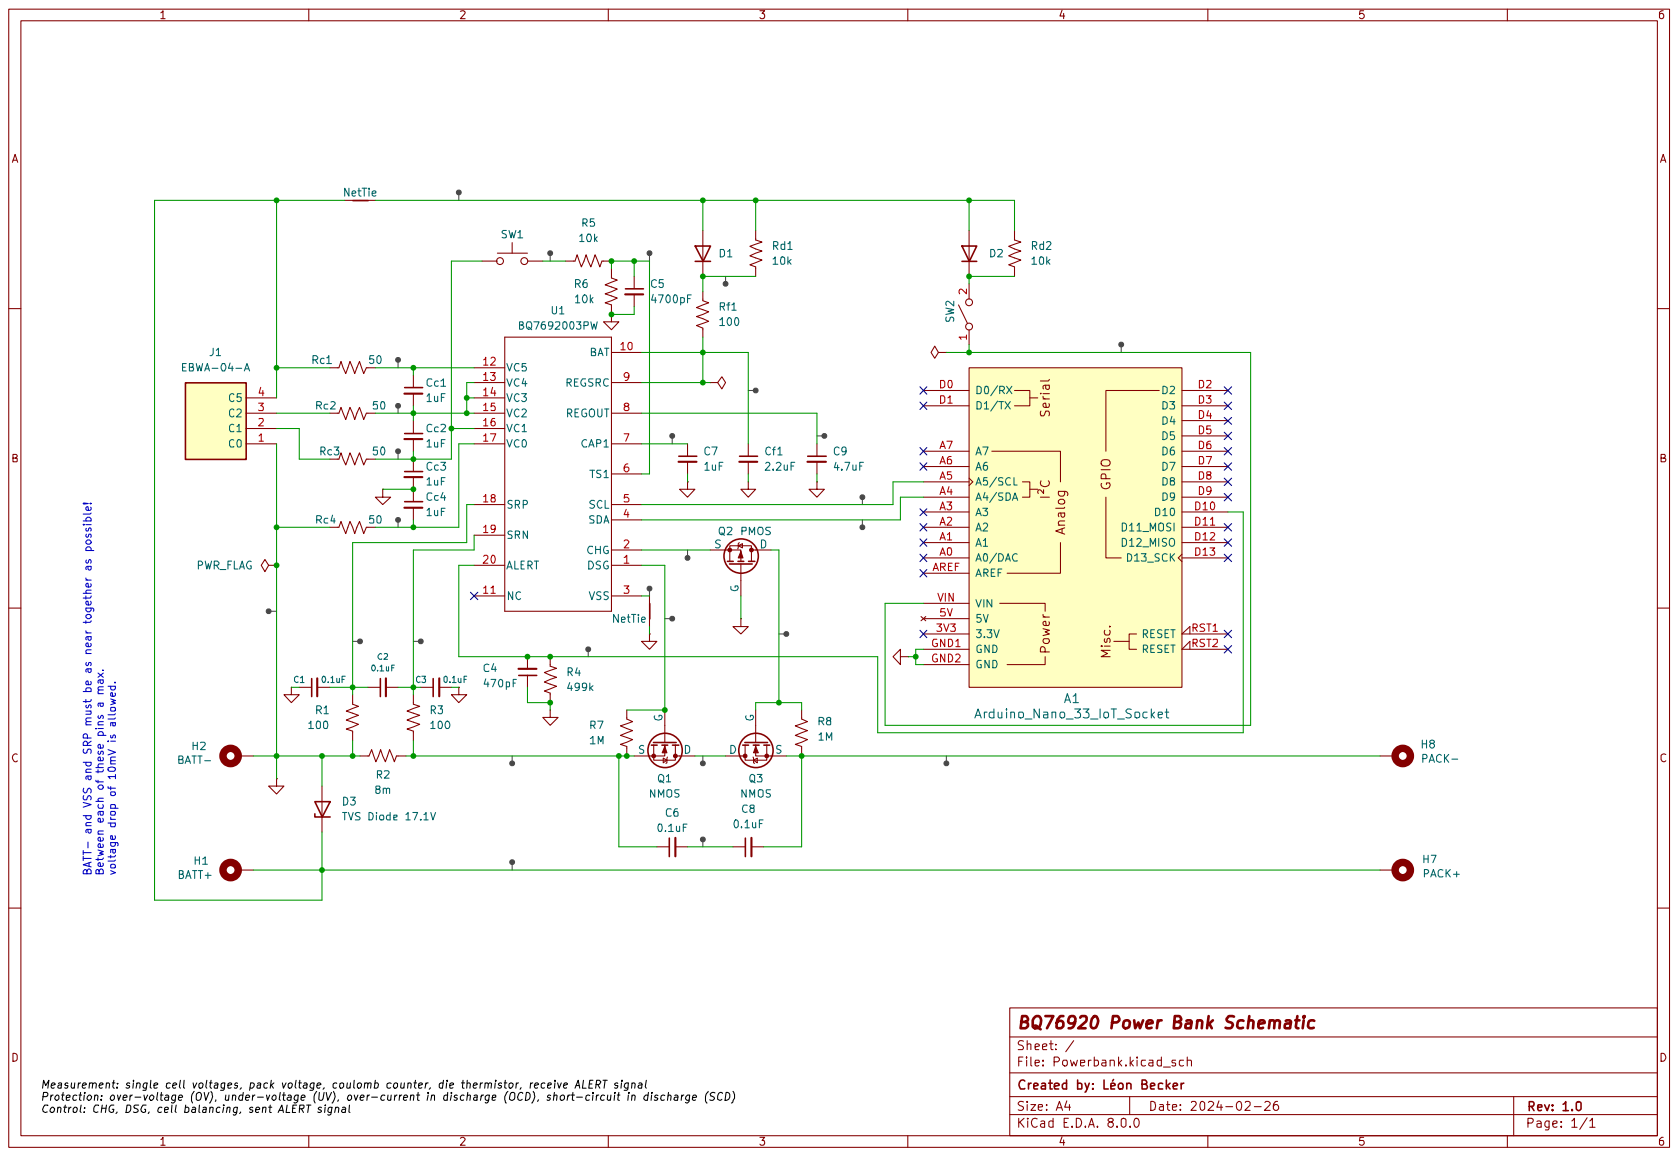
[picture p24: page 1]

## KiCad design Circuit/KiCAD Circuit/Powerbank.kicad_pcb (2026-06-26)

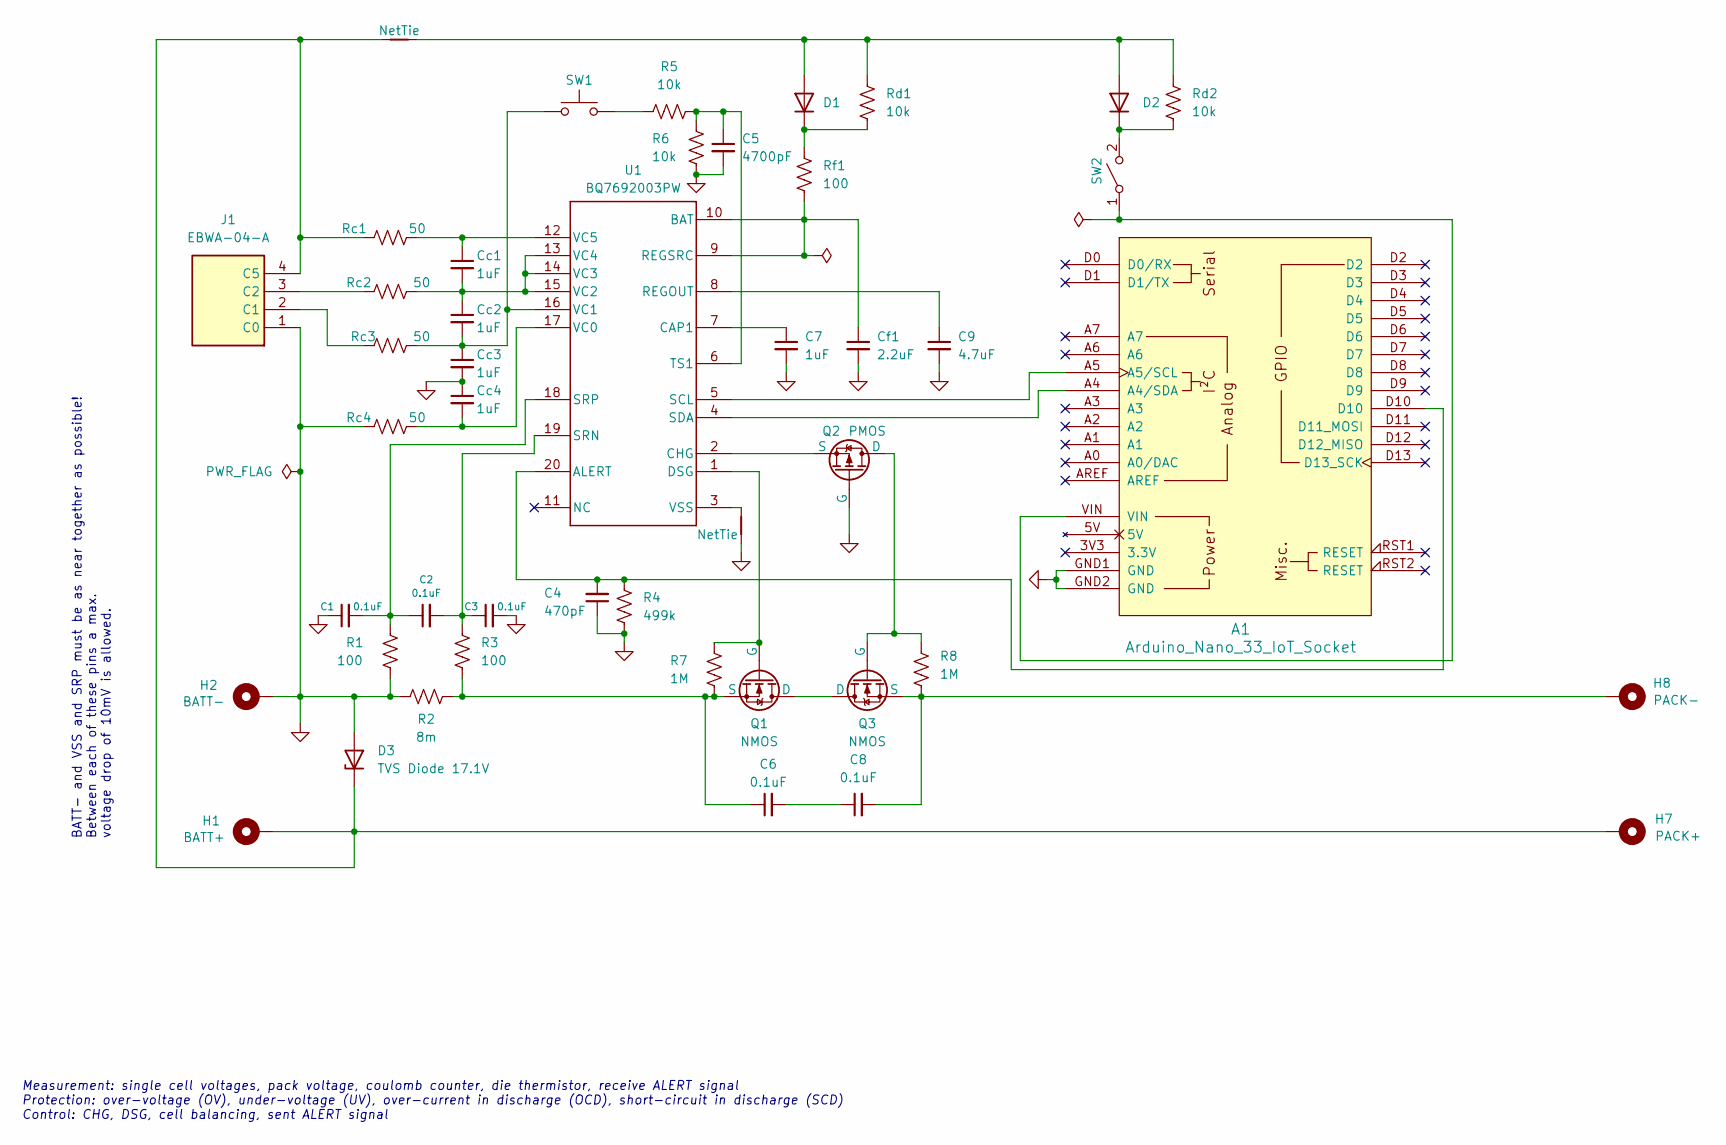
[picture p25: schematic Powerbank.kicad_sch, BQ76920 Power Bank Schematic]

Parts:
A1: Arduino_Nano_33_IoT_Socket
C1, C2, C3, C6, C8: 0.1uF; K104K10X7RF53H5_VIS; Mouser 594-K104K10X7RF53H5
C4: 470pF; K471K10X7RF5UH5_VIS; Mouser 594-K471K10X7RF5UH5
C5: 4700pF; CAP_C410C_AX_X7R_AXIMAX_KEM; Mouser 80-C410C472K1R
C7: 1uF; K105K20X7RF5TH5_VIS; Mouser 594-K105K20X7RF5TH5
C9: 4.7uF; CAP_FG24_TDK; Mouser 810-FG24X7R1E475KRT6
Cc1, Cc2, Cc3, Cc4: 1uF; K105K20X7RF5TH5_VIS; Mouser 594-K105K20X7RF5TH5
Cf1: 2.2uF; CAP_FG18_TDK; Mouser 810-FG18X5R1E225KRT6
D1, D2: D; 1N4149TR; Mouser 512-1N4149
D3: TVS Diode 17.1V; D_DO-41_SOD81_P7.62mm_Horizontal; Mouser 576-P4KE20A
H1: BATT+; Power Connection Pads
H2: BATT-; Power Connection Pads
H7: PACK+; Power Connection Pads
H8: PACK-; Power Connection Pads
J1: EBWA-04-A; Manufacturer_Part_Number EBWA-04-A; Mouser 737-EBWA-04-A
NT1, NT2: NetTie; NetTie General Net Class
Q1, Q3: NMOS; IRLB4132PBF; Mouser 942-IRLB4132PBF
Q2: PMOS; TO-92_MC_MCH; Mouser 689-VP3203N3-G
R1, R3: 100; STA_RNF14_STP; Mouser 708-RNF14FTD100R
R2: 8m; RES_14A_OHM; Mouser 588-14AFR008E
R4: 499k; YAG_MF25_YAG; Mouser 603-MFR-25FBF52-499K
R5, R6: 10k; STA_RNF18_STP; Mouser 708-RNF18FTD10K0
R7, R8: 1M; YAG_MF25_YAG; Mouser 603-MFR-25FRF521M
Rc1, Rc2, Rc3, Rc4: 50; RES_CMF07_VIS; Mouser 71-CMF5550R000FKEK70
Rd1, Rd2: 10k; STA_RNF18_STP; Mouser 708-RNF18FTD10K0
Rf1: 100; STA_RNF14_STP; Mouser 708-RNF14FTD100R
SW1: SW_Push; Switch Pads
SW2: SW_SPST; Switch Pads
U1: BQ7692003PW; PW0020A_N; Mouser 595-BQ7692003PW

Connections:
GND: A1.GND1 (GND), A1.GND2 (GND), C1.1, C3.2, C4.1, C5.2, C7.2, C9.2, Cc3.2, Cc4.1, Cf1.2, D3.2 (A), H2.1, J1.1 (C0), NT2.1, Q2.2 (G), R1.2, R2.1, R4.2, R6.2, Rc4.1
unnamed: A1.A4 (A4/SDA), U1.4 (SDA)
unnamed: A1.A5 (A5/SCL), U1.5 (SCL)
unnamed: C6.2, C8.1
unnamed: D1.2 (A), D2.2 (A), NT1.2, Rd1.1, Rd2.1
unnamed: D1.1 (K), Rd1.2, Rf1.1
unnamed: D2.1 (K), Rd2.2, SW2.2 (B)
unnamed: D3.1 (K), H1.1, H7.1, J1.4 (C5), NT1.1, Rc1.1
unnamed: J1.2 (C1), Rc3.1
unnamed: J1.3 (C2), Rc2.1
unnamed: Q1.1 (D), Q3.1 (D)
unnamed: Q1.2 (G), R7.1, U1.1 (DSG)
unnamed: C6.1, Q1.3 (S), R2.2, R3.2, R7.2
unnamed: Q2.1 (D), Q3.2 (G), R8.1
unnamed: Q2.3 (S), U1.2 (CHG)
unnamed: C8.2, H8.1, Q3.3 (S), R8.2
unnamed: R5.1, SW1.2
unnamed: A1.VIN, SW2.1 (A)
unnamed: A1.D10, C4.2, R4.1, U1.20 (ALERT)
unnamed: Cf1.1, Rf1.2, U1.9 (REGSRC), U1.10 (BAT)
unnamed: C7.1, U1.7 (CAP1)
unnamed: C9.1, U1.8 (REGOUT)
unnamed: C2.2, C3.1, R3.1, U1.19 (SRN)
unnamed: C1.2, C2.1, R1.1, U1.18 (SRP)
unnamed: C5.1, R5.2, R6.1, U1.6 (TS1)
unnamed: Cc4.2, Rc4.2, U1.17 (VC0)
unnamed: Cc2.2, Cc3.1, Rc3.2, SW1.1, U1.16 (VC1)
unnamed: Cc1.2, Cc2.1, Rc2.2, U1.13 (VC4), U1.14 (VC3), U1.15 (VC2)
unnamed: Cc1.1, Rc1.2, U1.12 (VC5)
unnamed: NT2.2, U1.3 (VSS)

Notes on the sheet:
BATT- and VSS and SRP must be as near together as possible! Between each of these pins a max. voltage drop of 10mV is allowed.
Measurement: single cell voltages, pack voltage, coulomb counter, die thermistor, receive ALERT signal Protection: over-voltage (OV), under-voltage (UV), over-current in discharge (OCD), short-circuit in discharge (SCD) Control: CHG, DSG, cell balancing, sent ALERT signal

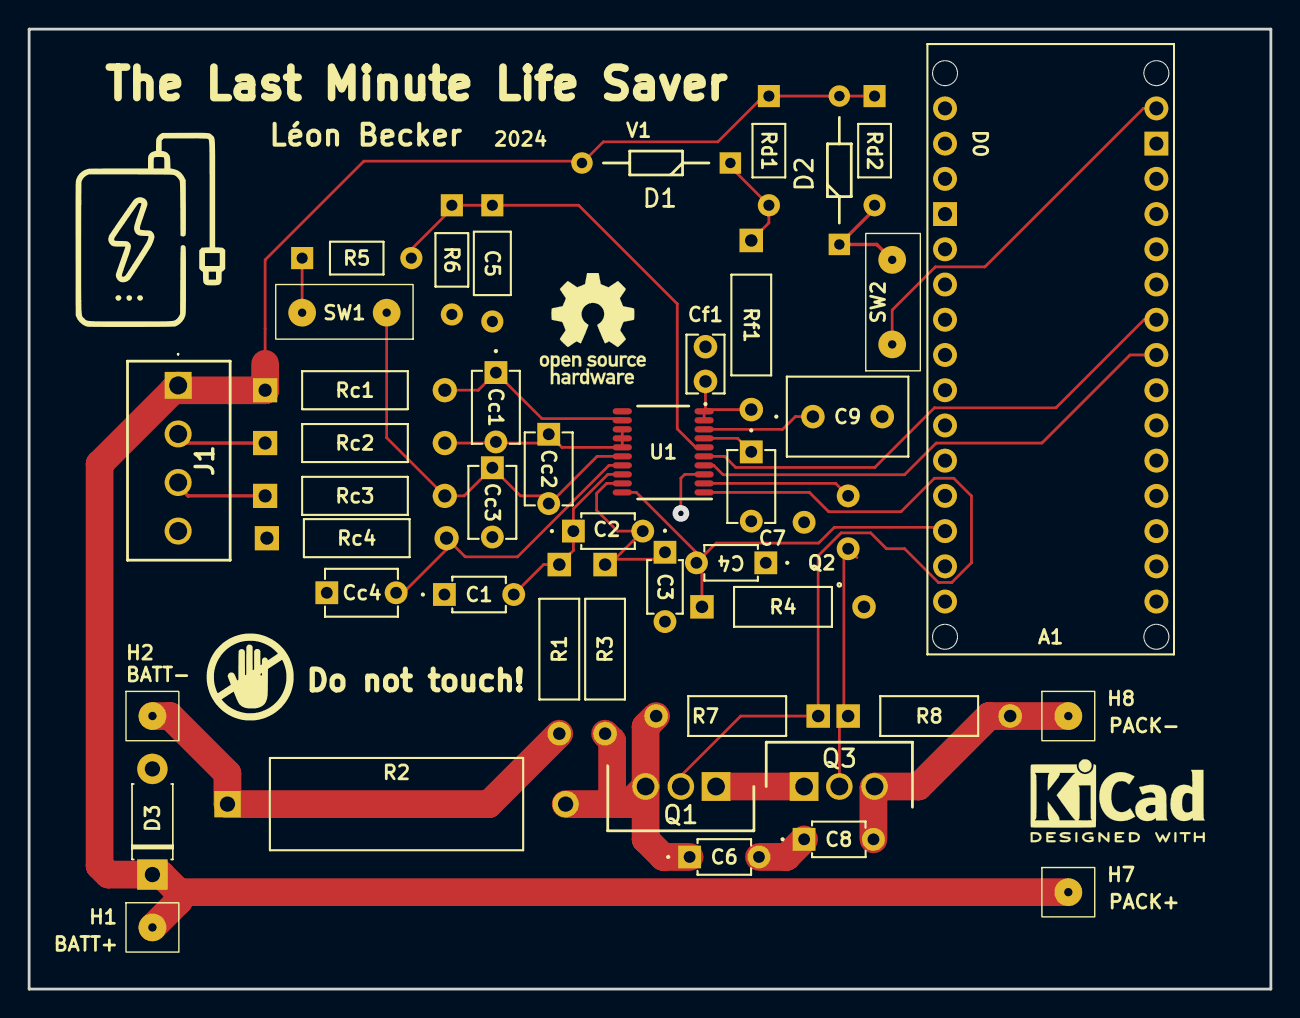
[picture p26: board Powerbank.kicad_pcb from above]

Board: 2 copper layers, 89.5 x 69.2 mm, 49 parts (0 on the bottom side), 30 nets.

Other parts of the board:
G1: LOGO; Do Not Touch Symbol
G2: OSHW-Logo_7.5x8mm_SilkScreen
REF1: KiCad-Logo2_5mm_SilkScreen

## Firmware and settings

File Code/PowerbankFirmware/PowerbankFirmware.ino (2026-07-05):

/*
  The Last Minute Life Saver Power Bank

  Hobby-grade supervisor firmware for the Arduino Nano 33 BLE + BQ76920 PCB.
  The BQ76920 remains the protection AFE; this firmware owns policy, telemetry,
  idle output control, guarded commands, and BLE.
*/

#include <ArduinoLog.h>
#include <Wire.h>
#include <mbed.h>

#include "balancer.h"
#include "bleApp.h"
#include "bq76920Driver.h"
#include "packMonitor.h"
#include "persistentStore.h"
#include "powerManager.h"
#include "safetyPolicy.h"
#include "serialConsole.h"
#include "utils.h"

Bq76920Driver bq;
PackMonitor monitor;
SafetyPolicy safetyPolicy;
Balancer balancer;
PowerManager powerManager;
BLEApp bleApp;
SerialConsole serialConsole;
PersistentStore persistentStore;
ControlState controls;
PolicyDecision lastDecision;

bool bqOnline = false;
bool bleOnline = false;

bool handleCommand(CommandId command, bool confirmed, char* result, size_t resultSize);
bool initializeBq();
void refreshAndApply();
void applyDecision(const PolicyDecision& decision);
void setBqOffline(const char* reason);
void logPeriodicStatus();
uint16_t telemetryFlags();
void maybeMaintenanceReboot();
void enterSystemOff();

void setup() {
    Serial.begin(9600);
    unsigned long serialWaitStartMs = millis();
    while (!Serial && millis() - serialWaitStartMs < 3000) {
        delay(10);
    }
    Log.begin(LOG_LEVEL_VERBOSE, &Serial);
    serialConsole.begin();

    Wire.begin();
    Wire.setClock(100000);
    pinMode(ALERT_PIN, INPUT);

    // The Nano 33 BLE power LED hangs on a GPIO and the core lights it at boot;
    // it costs about 1 mA around the clock, which the pack pays for. The RGB
    // LED is active-low, so park those pins high to keep it dark.
    pinMode(LED_PWR, OUTPUT);
    digitalWrite(LED_PWR, LOW);
    pinMode(LED_BUILTIN, OUTPUT);
    digitalWrite(LED_BUILTIN, LOW);
    pinMode(LEDR, OUTPUT);
    digitalWrite(LEDR, HIGH);
    pinMode(LEDG, OUTPUT);
    digitalWrite(LEDG, HIGH);
    pinMode(LEDB, OUTPUT);
    digitalWrite(LEDB, HIGH);

    Log.noticeln("\n************* The Last Minute Life Saver Power Bank *************");
    Log.noticeln("Firmware %s; BLE protocol %d", FIRMWARE_VERSION, BLE_PROTOCOL_VERSION);
    Log.noticeln("Type 'help' for serial commands.");

    bqOnline = initializeBq();
    persistentStore.begin(monitor);
    persistentStore.restoreControls(controls);
    if (controls.idleOutputOff) {
        powerManager.restoreIdleElapsed(persistentStore.savedIdleElapsedSec());
    }
    bleOnline = bleApp.begin();
    bleApp.attachStore(&persistentStore);

    // Last line of defense against a hung loop or a wedged BLE stack. Started
    // after the slow init work (flash mount can reformat) so it cannot bite
    // during setup.
    mbed::Watchdog::get_instance().start(thresholds::watchdogTimeoutMs);
}

void loop() {
    mbed::Watchdog::get_instance().kick();
    serialConsole.poll(handleCommand, monitor, controls, bq);
    if (bleOnline) {
        bleApp.poll(handleCommand);
    }

    refreshAndApply();

    uint16_t idleRemainingSec = powerManager.idleRemainingSec(monitor.snapshot(), controls);
    bool chargeComplete = controls.chargeLatchedOff &&
        monitor.maxCellMv() >= thresholds::chargeStopMv;
    // Don't persist while the BQ is offline: setBqOffline() force-disables
    // everything as an in-session fail-safe, and freezing that into flash
    // would leave the output disabled across a recovery reboot.
    if (bq.isOnline()) {
        persistentStore.syncControls(controls);
    }
    persistentStore.setIdleElapsedSec(
        controls.idleOutputOff ? powerManager.idleDurationMs() / 1000UL : 0
    );
    persistentStore.update(monitor, monitor.snapshot(), telemetryFlags(), chargeComplete);

    if (bleOnline) {
        // Once the output has idled off nobody is nearby; a 2.5 s advertising
        // interval saves radio power and still connects within a few seconds.
        bleApp.setLowPowerAdvertising(controls.idleOutputOff);
        bleApp.update(
            monitor.snapshot(),
            monitor.socPercent(),
            monitor.chargeMahTenths(),
            balancer.active(),
            bleApp.connected(),
            controls,
            idleRemainingSec,
            powerManager.automaticShutdownOccurred(),
            balancer.timedOut()
        );
    }

    maybeMaintenanceReboot();
    logPeriodicStatus();
    delay(250);
}

bool initializeBq() {
    if (!bq.begin()) {
        setBqOffline("BQ76920 initialization failed.");
        return false;
    }
    controls = ControlState();
    Log.noticeln("BQ76920 startup complete.");
    return true;
}

void refreshAndApply() {
    if (!bq.isOnline()) {
        monitor.markBqOffline();
        bqOnline = false;
        return;
    }

    if (!monitor.update(bq)) {
        setBqOffline("BQ76920 update failed.");
        return;
    }

    powerManager.update(monitor.snapshot(), controls);
    lastDecision = safetyPolicy.evaluate(monitor.snapshot(), controls);
    monitor.applyPolicy(lastDecision.state, lastDecision.faults);
    applyDecision(lastDecision);
}

void applyDecision(const PolicyDecision& decision) {
    PackSnapshot snapshot = monitor.snapshot();

    if (decision.requestShip) {
        Log.warningln("Entering SHIP mode.");
        persistentStore.checkpoint(monitor, snapshot);
        bq.enterShipMode();
        controls.shipRequested = false;
        // The MCU is wired to the battery ahead of the BQ FETs, so SHIP alone
        // would leave it draining the cells at milliamp level until they are
        // deep-discharged. Take the MCU down with the BQ.
        if (bleOnline) {
            bleApp.shutdown(thresholds::bleShutdownDrainMs);
        }
        enterSystemOff();
        return;
    }

    bool chgOn = (snapshot.sysCtrl2 & (1 << (uint8_t) SysControlOpt::CHG_ON)) != 0;
    bool dsgOn = (snapshot.sysCtrl2 & (1 << (uint8_t) SysControlOpt::DSG_ON)) != 0;

    if (chgOn != decision.allowCharge) {
        if (!bq.setChargeEnabled(decision.allowCharge)) {
            setBqOffline("Failed to update charge FET.");
            return;
        }
    }
    if (dsgOn != decision.allowDischarge) {
        Log.noticeln(
            "Discharge FET -> %s; state=%d faults=0x%X trusted=%T current=%d mA pack=%d mV",
            decision.allowDischarge ? "ON" : "OFF",
            (uint8_t) decision.state,
            decision.faults,
            snapshot.trusted,
            snapshot.currentMa,
            snapshot.packMv
        );
        if (!bq.setDischargeEnabled(decision.allowDischarge)) {
            setBqOffline("Failed to update discharge FET.");
            return;
        }
    }

    if (!balancer.update(bq, snapshot, decision.allowBalancing)) {
        setBqOffline("Failed to update balancing.");
        return;
    }
}

bool handleCommand(CommandId command, bool confirmed, char* result, size_t resultSize) {
    if (resultSize > 0) {
        result[0] = '\0';
    }

    switch (command) {
        case CommandId::OutputOn:
            if (!bq.isOnline()) {
                snprintf(result, resultSize, "Output blocked: BQ offline");
                return false;
            }
            if (!monitor.snapshot().trusted) {
                snprintf(result, resultSize, "Output blocked: readings untrusted");
                return false;
            }
            powerManager.noteOutputOn(controls);
            controls.dischargeManuallyDisabled = false;
            snprintf(result, resultSize, "Output on requested");
            return true;

        case CommandId::OutputOff:
            controls.dischargeManuallyDisabled = true;
            powerManager.noteOutputOff(controls);
            bq.setDischargeEnabled(false);
            snprintf(result, resultSize, "Output off");
            return true;

        case CommandId::ClearFaults:
            if (!bq.clearFaults()) {
                snprintf(result, resultSize, "Failed to clear faults");
                return false;
            }
            controls.dischargeLatchedOff = false;
            controls.chargeLatchedOff = false;
            snprintf(result, resultSize, "Fault clear sent");
            return true;

        case CommandId::Ship:
            if (!confirmed) {
                snprintf(result, resultSize, "SHIP requires confirmation");
                return false;
            }
            controls.shipRequested = true;
            snprintf(result, resultSize, "SHIP requested");
            return true;

        case CommandId::BalanceOff:
            if (!balancer.stop(bq)) {
                snprintf(result, resultSize, "Failed to disable balancing");
                return false;
            }
            balancer.clearTimeout();
            snprintf(result, resultSize, "Balancing off");
            return true;

        case CommandId::ChargeOn:
            if (!confirmed) {
                snprintf(result, resultSize, "charge_on requires developer confirmation");
                return false;
            }
            controls.chargeManuallyDisabled = false;
            snprintf(result, resultSize, "Charge enabled if safe");
            return true;

        case CommandId::ChargeOff:
            controls.chargeManuallyDisabled = true;
            bq.setChargeEnabled(false);
            snprintf(result, resultSize, "Charge off");
            return true;

        case CommandId::DischargeOn:
            if (!confirmed) {
                snprintf(result, resultSize, "discharge_on requires developer confirmation");
                return false;
            }
            controls.dischargeManuallyDisabled = false;
            controls.idleOutputOff = false;
            snprintf(result, resultSize, "Discharge enabled if safe");
            return true;

        case CommandId::DischargeOff:
            controls.dischargeManuallyDisabled = true;
            bq.setDischargeEnabled(false);
            snprintf(result, resultSize, "Discharge off");
            return true;

        case CommandId::RawDiagnostics:
            snprintf(result, resultSize, "Raw diagnostics available over serial");
            return true;

        case CommandId::ResetLearnedBattery:
            if (!confirmed) {
                snprintf(result, resultSize, "Battery reset requires confirmation");
                return false;
            }
            balancer.clearTimeout();
            persistentStore.resetLearnedBattery(monitor);
            snprintf(result, resultSize, "Learned battery data reset");
            return true;

        case CommandId::None:
        default:
            snprintf(result, resultSize, "Unknown command");
            return false;
    }
}

uint16_t telemetryFlags() {
    const PackSnapshot& snapshot = monitor.snapshot();
    uint16_t flags = 0;
    if (snapshot.trusted) flags |= FLAG_MEASUREMENTS_TRUSTED;
    if (snapshot.sysCtrl2 & (1 << (uint8_t) SysControlOpt::CHG_ON)) flags |= FLAG_CHG_ON;
    if (snapshot.sysCtrl2 & (1 << (uint8_t) SysControlOpt::DSG_ON)) flags |= FLAG_DSG_ON;
    if (controls.chargeManuallyDisabled) flags |= FLAG_MANUAL_CHARGE_OFF;
    if (controls.dischargeManuallyDisabled) flags |= FLAG_MANUAL_DISCHARGE_OFF;
    if (powerManager.automaticShutdownOccurred()) flags |= FLAG_IDLE_OUTPUT_OFF;
    if (balancer.active()) flags |= FLAG_BALANCING;
    if (snapshot.lowCellWarning) flags |= FLAG_LOW_CELL_WARN;
    if (snapshot.stale) flags |= FLAG_STALE;
    if (bleApp.connected()) flags |= FLAG_BLE_CONNECTED;
    if (controls.chargeLatchedOff && monitor.maxCellMv() >= thresholds::chargeStopMv) {
        flags |= FLAG_CHARGE_COMPLETE;
    }
    if (balancer.timedOut()) flags |= FLAG_BALANCE_TIMEOUT;
    return flags;
}

void setBqOffline(const char* reason) {
    bq.markOffline();
    monitor.markBqOffline();
    controls.chargeManuallyDisabled = true;
    controls.dischargeManuallyDisabled = true;
    controls.idleOutputOff = true;
    bqOnline = false;
    Log.errorln("%s", reason);
}

void maybeMaintenanceReboot() {
    // Self-heal for a silently wedged BLE stack: restart once a day, but only
    // when nothing would notice — no central connected, no current flowing, no
    // balancing. Manual switch states and the very-long-idle ship countdown
    // survive the restart via the persistent store, so a reboot can neither
    // re-enable a switched-off output nor postpone SHIP.
    if (millis() < thresholds::maintenanceRebootMs) {
        return;
    }
    if (bleOnline && bleApp.connected()) {
        return;
    }
    const PackSnapshot& snapshot = monitor.snapshot();
    if (abs(snapshot.currentMa) > thresholds::idleCurrentMa || balancer.active()) {
        return;
    }
    Log.warningln("Maintenance reboot to refresh the BLE stack.");
    persistentStore.checkpoint(monitor, snapshot);
    Serial.flush();
    delay(100);
    NVIC_SystemReset();
}

void enterSystemOff() {
    Log.warningln("MCU entering deep sleep. Cycle the power switch to restart.");
    Serial.flush();
    delay(100);
    NRF_POWER->SYSTEMOFF = 1;
    // Not reached; if System OFF ever failed, the watchdog resets us instead.
    while (true) {
        delay(1000);
    }
}

void logPeriodicStatus() {
    static unsigned long previousLogMs = 0;
    every(5000, &previousLogMs, []() {
        const PackSnapshot& snapshot = monitor.snapshot();
        Log.noticeln("Pack state: %d; trusted: %T; DSG: %T; CHG: %T; current: %d mA; pack: %d mV; Cell 1: %d mV; Cell 2: %d mV; Cell 5: %d mV; faults: 0x%X",
            (uint8_t) snapshot.state,
            snapshot.trusted,
            (snapshot.sysCtrl2 & (1 << (uint8_t) SysControlOpt::DSG_ON)) != 0,
            (snapshot.sysCtrl2 & (1 << (uint8_t) SysControlOpt::CHG_ON)) != 0,
            snapshot.currentMa,
            snapshot.packMv,
            snapshot.cell1Mv,
            snapshot.cell2Mv,
            snapshot.cell5Mv,
            snapshot.faultFlags);
    });
}

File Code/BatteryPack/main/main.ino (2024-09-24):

/*
This code is very specific to this project and only supports the used components in the
given configuration.
*/

#include <algorithm>
#include <ArduinoLog.h>
#include <cstdint>
#include <functional>
#include <stdlib.h>
#include <unordered_map>
#include <vector>
#include <Wire.h>

#include "batteryPack.h"
#include "bleApp.h"
#include "register.h"
#include "utils.h"

BatteryPack pack;

bool faultHandled = false;
// BLEApp bleApp;

// Runs once
void setup() {
    Serial.begin(9600);
    while(!Serial && !Serial.available()){}
    Log.begin(LOG_LEVEL_VERBOSE, &Serial);

    // bleApp.setup();
    Wire.begin(); // Must be executed inside the main.ino file, not any other included file etc.. Otherwise the Arduino will crash due to some reason.
	Wire.setClock(100000);

    Log.noticeln("\n************* The Last Minute Life Saver Power Bank *************");
    Log.noticeln("Assuming that the BQ76920 device is booted.");

    // Write CC_CFG register
    writeRegister(I2C_BQ76920_ADDRESS, registerMap::CC_CFG, 0x19);
    if (readRegister(I2C_BQ76920_ADDRESS, registerMap::CC_CFG) != 0x19) { // Check if writing was successful by reading CC_CFG back again.
        Log.fatalln("CC_CFG doesn't contain the expected data.");
        exit(1);
    } else {
        Log.noticeln("CC_CFG verification successful. Connection established.");
    };
    delay(250); // 250ms delay because of the transition from NORMAL mode to SHIP mode

    pack.readOffsetAndGain();
    Log.verboseln("ADC offset: %d; ADC gain: %d", pack.adcOffset, pack.adcGain);

    // The circuit that is permanently connected to PACK+ and PACK- will draw some high current for a short time on start up because some capacitors
    // of the connected circuit will charge. It's important to configure protection before turning on the CHG and DSG FETs because
    // the standard protection thresholds are too low to account for the current drawn by the capacitors.
    pack.pushProtection();
    pack.pushControl();
    pack.pushBalancing();
    Log.noticeln("Start up complete.\n");
}

// Runs repeatedly
void loop() {
    if (pack.state.currentState == BatteryState::State::SHIPMode) {
        Log.noticeln("Pack in SHIP mode.");
        delay(3000);
        return;
    }
    pack.updateTemperature();
    if (!(pack.temp >= -35.0f && pack.temp <= 60.0f)) {
        Log.warning("Internal die temperature outside of operating bounds: %F.", pack.temp);
        pack.transitionToSHIPMode();
        return;
    }

    // Local copies of registers must be updated to reflect possible changes the IC has made.
    pack.updateSysStatus();
    pack.updateSysControl();
    pack.updateVoltages();
    pack.updateCurrent();
    
    static unsigned long statePreviousMillis = 0;
    every(5000, &statePreviousMillis, []() {
        Log.noticeln("Pack state: %s; DSG: %T; CHG: %T; pack current: %d; pack voltage: %d (Cell 1: %d; Cell 2: %d; Cell 5: %d)", pack.state.getStringRepresentation().c_str(), pack.sysControl2[SysControlOpt::DSG_ON], pack.sysControl2[SysControlOpt::CHG_ON], 
                    pack.current, pack.voltage, pack.voltages[registerMap::VC1_HI], pack.voltages[registerMap::VC2_HI], pack.voltages[registerMap::VC5_HI]);
    });

    // Serial input
    if (Serial.available()) {
        String command = Serial.readStringUntil('\n');
        if (command == "balance") {
            pack.sysControl2[SysControlOpt::DSG_ON] = false;
            pack.sysControl2[SysControlOpt::CHG_ON] = false;
            pack.pushControl();
            pack.balanceCells[BalanceOpt::CB2] = true;
            pack.pushBalancing();
        } else if (command == "ship_mode") {
            pack.transitionToSHIPMode();
        } else if (command == "clear_scd") {
            writeRegister(I2C_BQ76920_ADDRESS, registerMap::SYS_STAT, 0b00000010);
        }
    }

    if (pack.sysStatus[SysStatusOpt::UV] == true || pack.sysStatus[SysStatusOpt::OV] == true ||
        pack.sysStatus[SysStatusOpt::SCD] == true || pack.sysStatus[SysStatusOpt::OCD] == true)
    {
        if (!faultHandled) {
            Log.noticeln("Fault occurred.");
            handleSysStatusFault(pack);
            faultHandled = true;
        }
        delay(500);
        return;
    } else {
        if (faultHandled == true) {
            Log.noticeln("Fault cleared.");
            faultHandled = false;
        }
    }

    performBatteryState(pack);
 
    // Keep at end of loop function
    // bleApp.loop();

    delay(500);
}

// Turns off charge, discharge and balancing.
void handleSysStatusFault(BatteryPack &pack) {
    // Does the same for UV, OV, SCD and OCD events.
    std::map<SysStatusOpt, bool> &status = pack.sysStatus;
    Log.error("System status fault detected. ");
    Log.error("[UV: %T, OV: %T] ", status[SysStatusOpt::UV], status[SysStatusOpt::OV]);
    Log.errorln("[SCD: %T, OCD: %T]", status[SysStatusOpt::SCD], status[SysStatusOpt::OCD]);
    pack.sysControl2[SysControlOpt::DSG_ON] = false;
    pack.sysControl2[SysControlOpt::CHG_ON] = false;
    pack.pushControl();
    for (auto &entry : pack.balanceCells) {
        entry.second = false;
    }
    pack.pushBalancing();
}
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

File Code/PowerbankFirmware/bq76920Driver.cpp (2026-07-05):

#include <ArduinoLog.h>

#include "bq76920Driver.h"
#include "utils.h"

bool Bq76920Driver::begin() {
    online = false;
    cachedSysCtrl1 = (1 << (uint8_t) SysControlOpt::ADC_EN);
    // FETs stay off at init; the safety policy enables them once readings are
    // trusted. Otherwise every reboot would briefly power the output even when
    // it was manually or automatically switched off before the restart.
    cachedSysCtrl2 = (1 << (uint8_t) SysControlOpt::CC_EN);
    cachedCellBal = 0;

    if (!writeRegister(I2C_BQ76920_ADDRESS, registerMap::CC_CFG, 0x19)) {
        return false;
    }
    uint8_t ccConfig = 0;
    if (!readRegister(I2C_BQ76920_ADDRESS, registerMap::CC_CFG, &ccConfig) || ccConfig != 0x19) {
        Log.errorln("CC_CFG verification failed.");
        return false;
    }
    delay(250);

    if (!readOffsetAndGain()) {
        return false;
    }
    if (!pushProtection()) {
        return false;
    }
    if (!clearFaults()) {
        return false;
    }
    if (!pushControl()) {
        return false;
    }
    if (!disableBalancing()) {
        return false;
    }

    online = true;
    return true;
}

bool Bq76920Driver::isOnline() const {
    return online;
}

void Bq76920Driver::markOffline() {
    online = false;
}

bool Bq76920Driver::readOffsetAndGain() {
    uint8_t offset = 0;
    uint8_t gain1 = 0;
    uint8_t gain2 = 0;
    if (!readRegister(I2C_BQ76920_ADDRESS, registerMap::ADCOFFSET, &offset) ||
        !readRegister(I2C_BQ76920_ADDRESS, registerMap::ADCGAIN1, &gain1) ||
        !readRegister(I2C_BQ76920_ADDRESS, registerMap::ADCGAIN2, &gain2))
    {
        return false;
    }

    adcOffsetUv = (int8_t) offset;
    adcGainUvPerLsb = 365 + (((gain1 & 0b00001100) << 1) | ((gain2 & 0b11100000) >> 5));
    Log.noticeln("BQ calibration: ADC offset %d uV; ADC gain %d uV/LSB", adcOffsetUv, adcGainUvPerLsb);
    return true;
}

bool Bq76920Driver::pushProtection() {
    uint8_t protect1Config = 0b00011111; // SCD: 400 us, 100 mV => about 12.5 A at 8 mOhm.
    uint8_t protect2Config = 0b01000111; // OCD: 160 ms, 28 mV => about 3.5 A.
    uint8_t protect3Config = 0b01010000; // UV delay 4s, OV delay 2s.
    uint8_t ovTripConfig = ((((unsigned long) thresholds::hardwareOvMv - adcOffsetUv) * 1000 / adcGainUvPerLsb) >> 4) & 0xFF;
    uint8_t uvTripConfig = ((((unsigned long) thresholds::hardwareUvMv - adcOffsetUv) * 1000 / adcGainUvPerLsb) >> 4) & 0xFF;

    bool written = writeRegister(I2C_BQ76920_ADDRESS, registerMap::PROTECT1, protect1Config) &&
        writeRegister(I2C_BQ76920_ADDRESS, registerMap::PROTECT2, protect2Config) &&
        writeRegister(I2C_BQ76920_ADDRESS, registerMap::PROTECT3, protect3Config) &&
        writeRegister(I2C_BQ76920_ADDRESS, registerMap::OV_TRIP, ovTripConfig) &&
        writeRegister(I2C_BQ76920_ADDRESS, registerMap::UV_TRIP, uvTripConfig);
    if (!written) {
        return false;
    }

    uint8_t protect2Readback = 0;
    if (!readRegister(I2C_BQ76920_ADDRESS, registerMap::PROTECT2, &protect2Readback)) {
        Log.errorln("PROTECT2 readback failed.");
        return false;
    }
    if (protect2Readback != protect2Config) {
        Log.errorln("PROTECT2 verification failed: wrote %X, read %X.", protect2Config, protect2Readback);
        return false;
    }

    Log.noticeln("BQ protection configured: PROTECT2=%X; OCD=3500 mA; delay=160 ms.", protect2Readback);
    return true;
}

bool Bq76920Driver::pushControl() {
    return writeSysCtrl1(cachedSysCtrl1) && writeSysCtrl2(cachedSysCtrl2);
}

bool Bq76920Driver::writeSysCtrl1(uint8_t value) {
    if (!writeRegister(I2C_BQ76920_ADDRESS, registerMap::SYS_CTRL1, value)) {
        online = false;
        return false;
    }
    cachedSysCtrl1 = value;
    return true;
}

bool Bq76920Driver::writeSysCtrl2(uint8_t value) {
    if (!writeRegister(I2C_BQ76920_ADDRESS, registerMap::SYS_CTRL2, value)) {
        online = false;
        return false;
    }
    cachedSysCtrl2 = value;
    uint8_t readback = 0;
    if (readRegister(I2C_BQ76920_ADDRESS, registerMap::SYS_CTRL2, &readback) && readback != value) {
        Log.warningln("SYS_CTRL2 write mismatch: wrote 0x%X, read 0x%X.", value, readback);
    }
    return true;
}

bool Bq76920Driver::readRaw14(uint8_t address, uint16_t& value) {
    uint8_t reading[2];
    if (!readRegisters(I2C_BQ76920_ADDRESS, address, reading, 2)) {
        online = false;
        return false;
    }
    value = (((uint16_t) reading[0] & 0b00111111) << 8) | reading[1];
    return true;
}

bool Bq76920Driver::readRaw16(uint8_t address, uint16_t& value) {
    uint8_t reading[2];
    if (!readRegisters(I2C_BQ76920_ADDRESS, address, reading, 2)) {
        online = false;
        return false;
    }
    value = ((uint16_t) reading[0] << 8) | reading[1];
    return true;
}

bool Bq76920Driver::readRaw(BqRawReadings& raw) {
    uint16_t cc = 0;
    if (!readRaw14(registerMap::VC1_HI, raw.vc1Raw) ||
        !readRaw14(registerMap::VC2_HI, raw.vc2Raw) ||
        !readRaw14(registerMap::VC5_HI, raw.vc5Raw) ||
        !readRaw16(registerMap::BAT_HI, raw.batRaw) ||
        !readRaw16(registerMap::CC_HI, cc) ||
        !readRaw14(registerMap::TS1_HI, raw.tempRaw) ||
        !readStatus(raw.sysStat) ||
        !readControl(raw.sysCtrl1, raw.sysCtrl2) ||
        !readCellBalancing(raw.cellBal))
    {
        online = false;
        return false;
    }
    raw.ccRaw = (int16_t) cc;
    online = true;
    return true;
}

bool Bq76920Driver::readStatus(uint8_t& sysStat) {
    if (!readRegister(I2C_BQ76920_ADDRESS, registerMap::SYS_STAT, &sysStat)) {
        online = false;
        return false;
    }
    return true;
}

bool Bq76920Driver::readControl(uint8_t& sysCtrl1, uint8_t& sysCtrl2) {
    uint8_t reading[2];
    if (!readRegisters(I2C_BQ76920_ADDRESS, registerMap::SYS_CTRL1, reading, 2)) {
        online = false;
        return false;
    }
    sysCtrl1 = reading[0];
    sysCtrl2 = reading[1];
    cachedSysCtrl1 = sysCtrl1;
    cachedSysCtrl2 = sysCtrl2;
    return true;
}

bool Bq76920Driver::readCellBalancing(uint8_t& cellBal) {
    if (!readRegister(I2C_BQ76920_ADDRESS, registerMap::CELLBAL1, &cellBal)) {
        online = false;
        return false;
    }
    cachedCellBal = cellBal;
    return true;
}

bool Bq76920Driver::clearFaults() {
    uint8_t faultMask = (1 << (uint8_t) SysStatusOpt::CC_READY) |
        (1 << (uint8_t) SysStatusOpt::DEVICE_XREADY) |
        (1 << (uint8_t) SysStatusOpt::OVRD_ALERT) |
        (1 << (uint8_t) SysStatusOpt::UV) |
        (1 << (uint8_t) SysStatusOpt::OV) |
        (1 << (uint8_t) SysStatusOpt::SCD) |
        (1 << (uint8_t) SysStatusOpt::OCD);
    return writeRegister(I2C_BQ76920_ADDRESS, registerMap::SYS_STAT, faultMask);
}

bool Bq76920Driver::setChargeEnabled(bool enabled) {
    if (enabled) {
        cachedSysCtrl2 |= (1 << (uint8_t) SysControlOpt::CHG_ON);
    } else {
        cachedSysCtrl2 &= ~(1 << (uint8_t) SysControlOpt::CHG_ON);
    }
    return writeSysCtrl2(cachedSysCtrl2);
}
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

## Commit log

2024-03-31 Fixed use of keyword "register"
    [utils.cpp]
2024-09-24 Added constant voltage charging.
2026-06-26 Restructured project and added firmware hardware map
    [Circuit.kicad_pcb, Circuit.kicad_sch, Powerbank.kicad_pcb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]
2026-06-26 Added help, status, ... commands to see state of powerbank
2026-06-26 Reworked power bank firmware.
    Does the same, but better.
    [PowerbankFirmware.ino, batteryPack.cpp, bq76920Driver.cpp]
2026-06-26 Added power bank app
2026-07-03 Added new case files
    [1x NCR18650B Protected Holder.stl, Base_Frame v157_Buck Converter Top.stl, Base_Frame v157_Cable Hub Top.stl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]
2026-07-03 Added alerts, history and battery health to the app
2026-07-04 Updated printed parts
    [Base_Frame v157_Main Body.stl, Case.3mf, Main Body Bottom Text.stl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]
2026-07-05 Updated printed parts to v169, removed KiCAD lock files
    [Base_Frame v157_Buck Converter Top.stl, Base_Frame v157_Cable Hub Top.stl, Base_Frame v157_Diode Cover.stl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]
2026-07-05 Firmware 0.4.0 power/BLE robustness, trend-based ETA and history rework
    Firmware:
    - LEDs off (power LED alone saved ~1 mA continuous)
    - SHIP now also puts the MCU into System OFF so the pack cannot
    deep-discharge the cells through the always-on Arduino supply
    - BLE self-heal: periodic re-advertise, hardware watchdog, daily
    idle maintenance reboot
    - Manual output/charge switches, charge latch and the 3-day ship
    countdown persist across reboots (state v2 with v1 migration)
    - FETs no longer force-on at BQ init; hardware UV backstop 2.70 V;
    usable capacity seed 3000 mAh
    App:
    - Time-to-full/empty from the coulomb counter trend instead of
    instantaneous current, taper-aware, using learne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
    [PowerbankFirmware.ino, bq76920Driver.cpp]
2026-07-05 History sync performance, slow idle advertising, ETA responsiveness and session details
    - HistoryStore now uses SwiftData predicate fetches instead of loading
    every sample per lookup (firmware history sync was O(n^2))
    - BLE advertising drops to a 2.5 s interval once the output has idled
    off, back to 100 ms whenever the pack is in use
    - ETA resets its trend on large load steps and seeds from the
    instantaneous current until the trend warms up
    - Session detail: transferred charge/energy summary and a shared
    scrub ruler across the current/voltage/temperature charts
    - Diagnostics shows the firmware boot number to make maintenance
    reboots observable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
    [PowerbankFirmware.ino, register.h]
2026-07-05 Combined CC/CV session chart and dark-mode scrubber fix
    - Session detail merges current and pack voltage into one chart with a
    secondary voltage axis (voltage rescaled into current-axis space)
    - Scrubber annotation uses an adaptive solid background; materials
    render black inside chart annotations in dark mode
